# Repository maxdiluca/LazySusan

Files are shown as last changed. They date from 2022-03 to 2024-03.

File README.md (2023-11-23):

# Arduino-based Lazy Susan

<p>This project has been funded by the Experimental Psychology Society and has been developed by <a href="https://massimilianodiluca.info/">Max Di Luca</a>.</p>

<p align="left">

 Judgments about material properties (e.g., roughness, softness, temperature extraction) are acquired through direct contact between skin with a surface and through exploration. Presenting materials to participant can be an exhausting task for the experimenter, and mechanical automation is a desired methodology. Moreover, due to social distancing requirements, in-person experiments to study how the perception of these properties is achieved, might not be possible. To overcome these limitations, here we devised a setup that can be either used to present objects to participants, it could be mailed to participants’ homes with instructions on how to run the experiment and collect the data, or that can be employed in conjunction with a VR headset to create visual-haptic discrepancies between material properties.
 
 The device is built by combining an inexpensive lazy Susan with a microcontroller (Atmega168). Precisely manufactured 3D printed surfaces are mounted on the motorized lazy Susan and the microcontroller allows rapid selection of the appropriate sample. 

 </p>
 <p align="left">
 <br>
 The code to control the experiment is included in this repository.
 
  </p>
 <p align="centre">

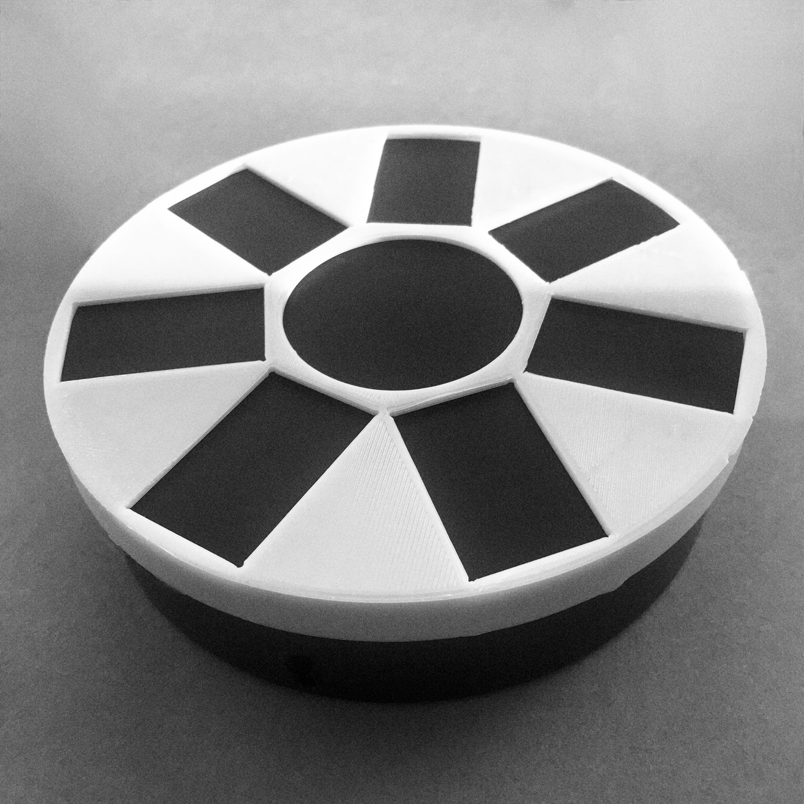
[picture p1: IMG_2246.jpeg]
 

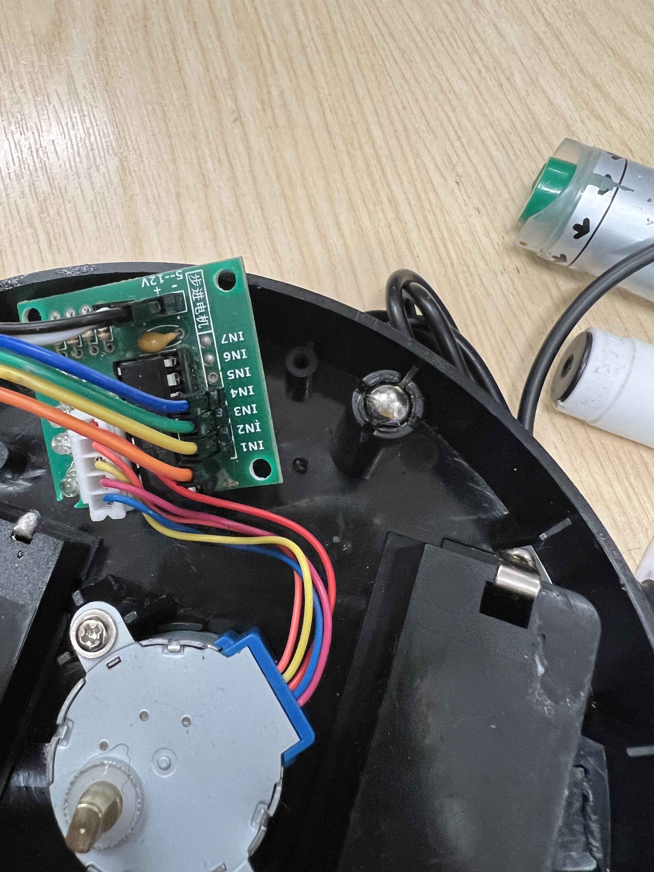
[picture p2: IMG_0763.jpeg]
  
  </p>
 <p align="centre">
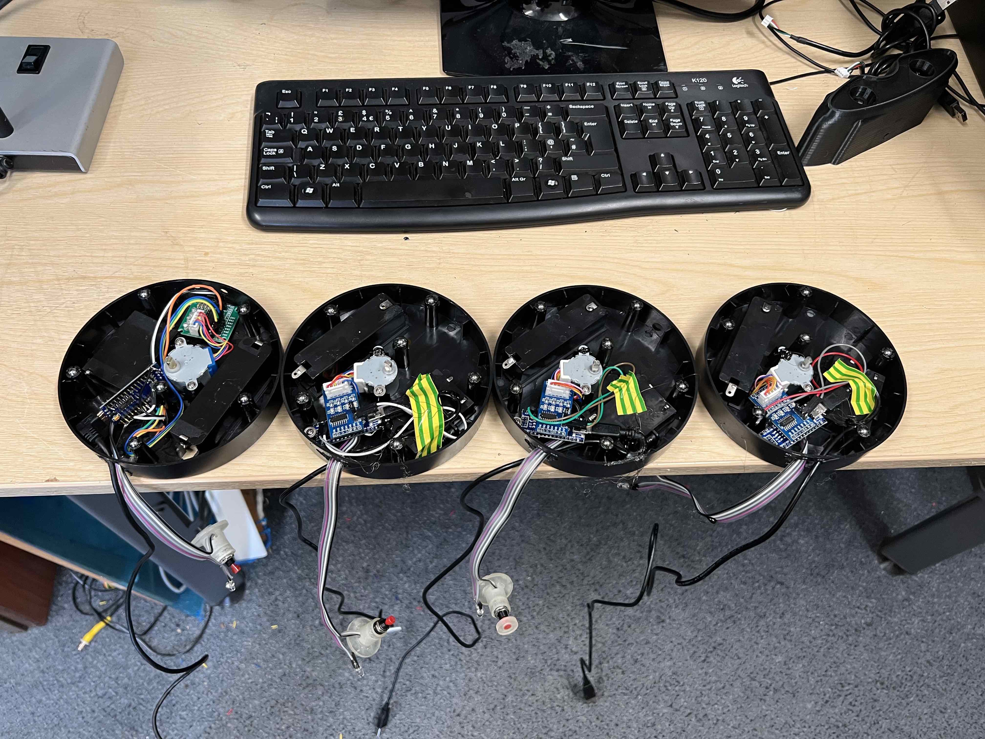
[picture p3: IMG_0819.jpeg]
   <br> 
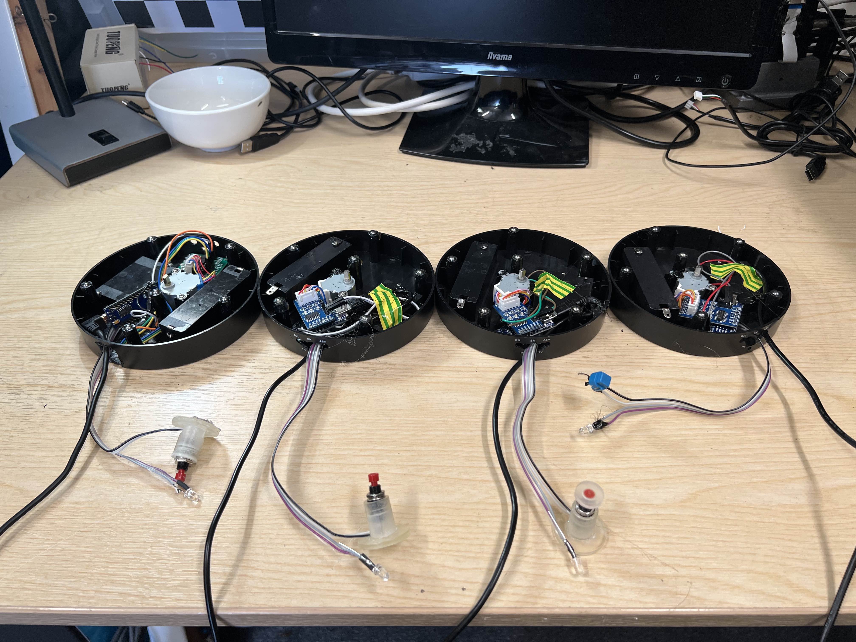
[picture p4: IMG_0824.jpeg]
    
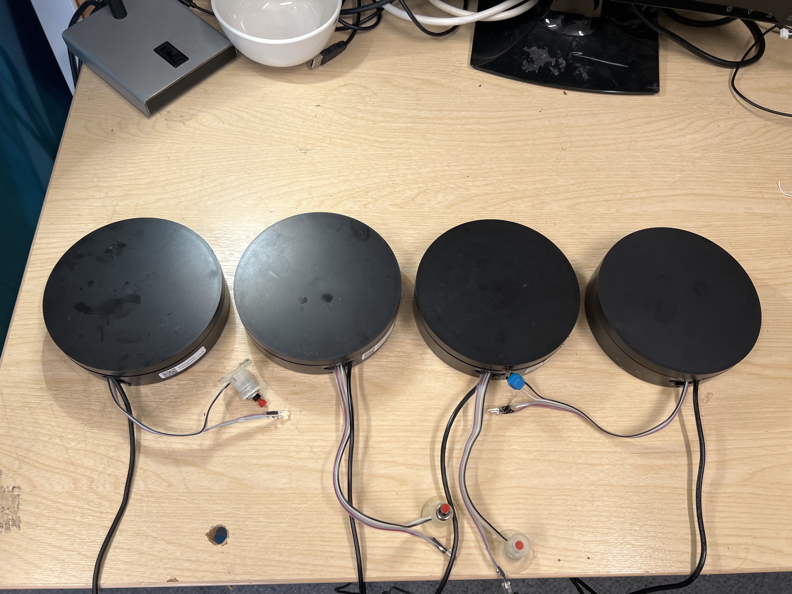
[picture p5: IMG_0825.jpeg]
    
   </p>
 <p align="centre">
  <br>
  
 <video controls="controls" width="420" height="315" name="Video Name">
  <source src="./IMG_0762.MOV">
</video>

  <br>
  <object data="http://www.youtube.com/embed/Hrc2zLRdNaU"
  width="420" height="315"></object>
 
</p>

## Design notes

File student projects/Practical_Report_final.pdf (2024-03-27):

## University of Birmingham

## School of Psychology

## Assessment Submission Form

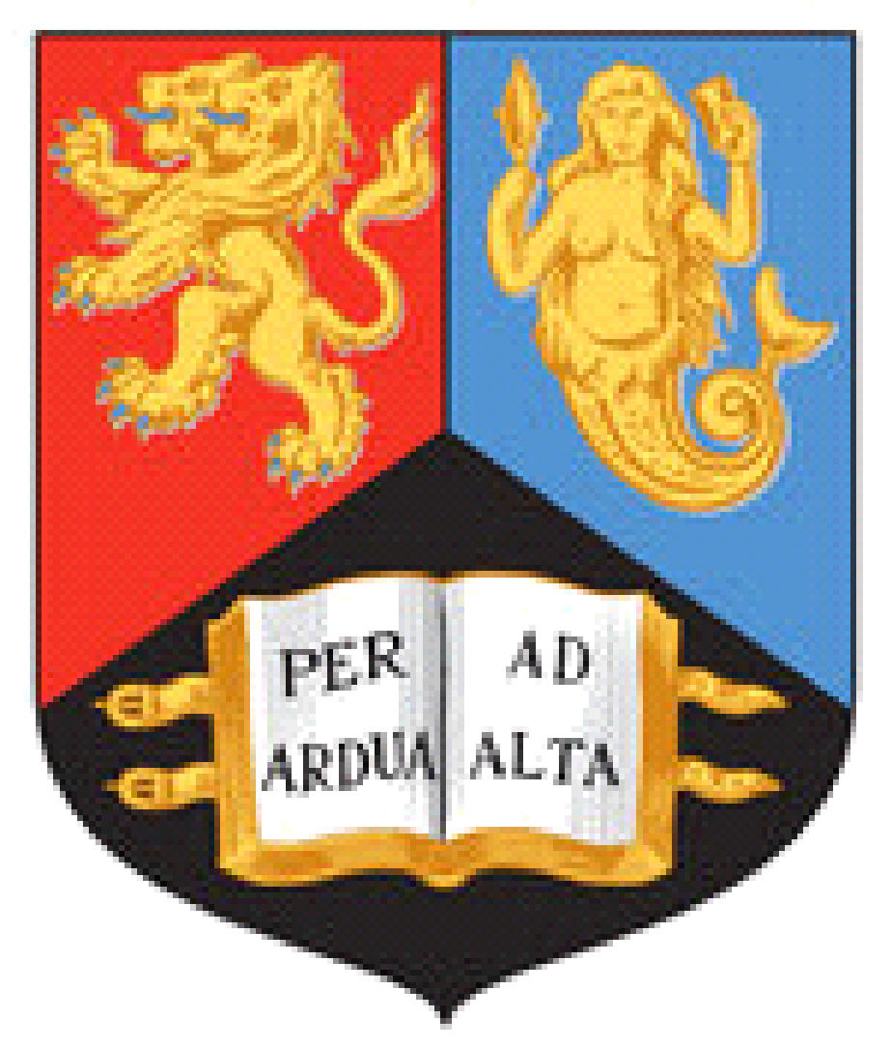
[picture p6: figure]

The purpose of this coversheet is to ensure you receive targeted feedback that will support your learning. Please complete all sections and use this template to start your written assignments.

Student ID: | 2261842
Programme: | Postgraduate
Module title: | Current Research and Practice

Assessment type:

Title of your report: | Arduino robot for tactile psychophysics
Word count: | 1739

I am happy for my assignment to be considered for inclusion as an anonymised
exemplar in the Psychology Bank of Assessed Work. | ☐ Yes | ☐ No

Reflection on previous feedback (max. 60 words):
Write a brief comment about something that you have tried to implement in the current piece in response to previous feedback: e.g. "I have been told that I need to include an opening paragraph that identifies the purpose of the piece. I have tried to address this here."

Request for particular attention to be paid (max. 60 words):
Identify an area for which you would particularly like feedback: e.g. “Please comment on the coherence of my piece as a whole. Are my arguments fully developed?”

Arduino robot for tactile psychophysics

2261842

School of Psychology

University of Birmingham

## Introduction

The primary purpose of this study is to obtain a basic understanding of phycological methods and Arduino programming to implement an experimental environment. Then, analyse the data to estimate perception judgement on Matlab. We have learned specific techniques to test sensory information like auditory sensation and tactile. Furthermore, the codes should be created enough to launch the open-source software project of this demonstration.

Psychophysics
Psychophysics has been the main focus of research for a long time as it is vital to investigate how perception is accomplished (Stevens, 1960).
The history of psychology started in 1824 by Johann Herbart, recognised as a father of educational psychology (Hoose, 2021). He was not a usual teacher that developed his method and taught it to the students. He highlighted the significance of the relationship between the physical environment and the state of mind. Then, some researchers had gradually solidified the concept of psychology; for example, weber studied the time of action by the weight of objects in 1834. As a whole, this subject is the part of science defining the relationship between physical occasions and psychological experiences—the purpose of this study is to solve these connections, not only the measurements. Some of the keywords in this subject are Quantitative and Objective to define the relationship (Ingleby, 1967). One of the good examples of quantitative is the situation during the class, as the number of photos on screen and brightness. Having this quantitative analysis, humans can explore inter-species or inter-subjects stimulus and perception. The sense of texture is one of the numerous essential research topics in this field, and the experiments carried out here deal with the subject accordingly.

Magnitude Estimation
Magnitude Estimation is one of the essential methods in psychology to create numerical data for the intensity of perception of physical stimuli such as sound and tactile (Huang and Griffin, 2014). Using this method, people can analyse the connection between biological information and perception. If the stimulus intensity will be two times larger than the previous one, the estimation rate should be twice as high (Luca, 2014). In this research, participants were tested by the Absolute Magnitude Estimation(AME) method, a type of Magnitude Estimation without reference information. They had to determine numerical values for roughness without any prior knowledge.

Weber–Fechner Law
A law that describes the different thresholds for sensory information was formalised by Weber in the early history of Psychology, which was in the nineteenth century. He was able to find that the threshold for discriminating a stimulus is balanced to its intensity. The intensity of a feeling is not subjective and can only be measured relatively. In other words, if the ratio of stimuli is the same in different situations, the difference in sensation received is to be equal (Nutter and Esker, 2006). This law is known as below:

ΔI/I = K

Where K is a constant, and I is the expected value of the stimulus.
Gustav Fechner expanded the law by emanating a relationship between a stimulus and the estimated magnitude (Stevens, 1961). According to the discovery, the rate of sensory quantity is inversely proportional to the intensity of the stimulus. Also, it is proportional to the increment of the stimulus. He derived the mathematical relationship from these relationships.

### P = K log I

Where K is constant, P is the perceived sensory, I is the intensity of stimuli. To conclude, he found that sensory volume is proportional to the logarithm of the stimulus volume. Currently, this law is called Weber–Fechner Law since this finding is based on Weber's law.

## Implementation

Arduino software
Arduino is an open-source software platform to write and read codes in microcontrollers connecting buttons, sensors, or motors(https://www.arduino.cc/en/Guide/Introduction). We can write codes in C++, which contains three main parts, functions, values, and structure. Thanks to the easiness of getting started experiments, quite a few people have used Arduino in recent years worldwide, not only for simple tasks but also for complicated scientific ones. There are some reasons why it has been chosen. One of the principal reasons is that the simple way of using this platform has allowed both teachers and students low cost. Moreover, developers do not need to prepare specific machines because they run on any operating system.

Establishing the environment
STM32 was used to create the environment for this experiment. This microcomputer delivers the basis for building embedded systems at affordable costs. Coding for this device is done using an Arduino, which may not be as good as the Arduino hardware in terms of detail. Still, it can basically provide the functionality needed for development (Ersin, 2022). This computer was programmed to use a stepper motor in the study, which revolved to set plates for the experiment.
Nonetheless, I had to attach an output device to it as there was only an input function.
For this reason, there were mainly three kinds of apparatus in this device: input board, output board, and stepper motor. The stepper motor has electrodes in each of the four directions. Increasing or decreasing the input value of each enables the reproduction of various movements, not only in the forward direction. The table type in this research is customarily called Lazy Susan, which is able to rotate to cope with the stepper motor's rotation. The table has four holes at 90 degrees intervals into which the boards used in the experiments are inserted.

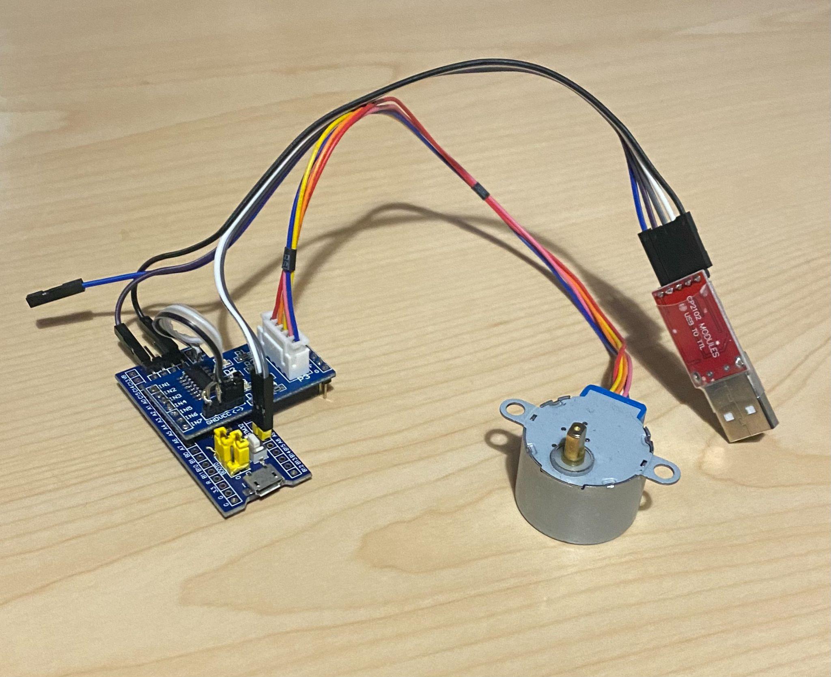
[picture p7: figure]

Picture1 STM32 device with Stepper motor

Programming
With regard to programming, I used Stepper.h function from Arduino, which enables us to use a stepper motor with ease. After setting the values to rotate at 90 degrees, the input ports connected to each direction are matched and initialised. The setup function determines the speed of the rotation.
The table was set to rotate in the loop function. After that, the motor was designed to rotate at regular intervals to trace the finger by setting the number of moving times.
Consequently, the experimental procedure is as follows:

1: Touch the board in front of the participant
2: Record the value of the surface roughness
2: Revolve the device at 90 degrees
3: Back to step 1 until one revolution

Actually, the practice is done before step 1. This practice has nothing to do with programming, so I will not go into detail but will explain it adequately later.

#include <Stepper.h>

const int stepsPerRotation = 514; //set the num to rotate 90 degrees per movement // initialize the stepper which uses from 1 to 4
Stepper myStepper(stepsPerRotation, 3, 1, 2, 4);

void setup() {
// set the speed at 30rpm: myStepper.setSpeed(30);
}

void loop() {
// step fixed degree in one direction: myStepper.step(stepsPerRotation); // make waiting time to touch the board delay(1500);

}

## Methodology

The roughness of the plates is from 1800mm to 4200mm, as shown in the following picture. Each plate has a shallow groove dug in the front made through a 3D printer. There were 6 participants in this experiment. They were instructed to answer how rough the surface was for four different plates using a scale from 1 to
10. In addition, they had to brush the plate just once by finger pad actively. Before the experiment, subjects practised understanding how to do it with a random sample, without any prior information about that sample. After that, the participants would check the roughness of the boards four times in a row with their eyes closed. The boards were placed on the lazy susan table that revolves to make plates located in front of the players. The number of times per board was used varied a little, as it was decided entirely at random which board to use. There was a difference of up to two times. However, as the number of times each board was used was close to the average, it was decided that this did not have any particular influence on the results.

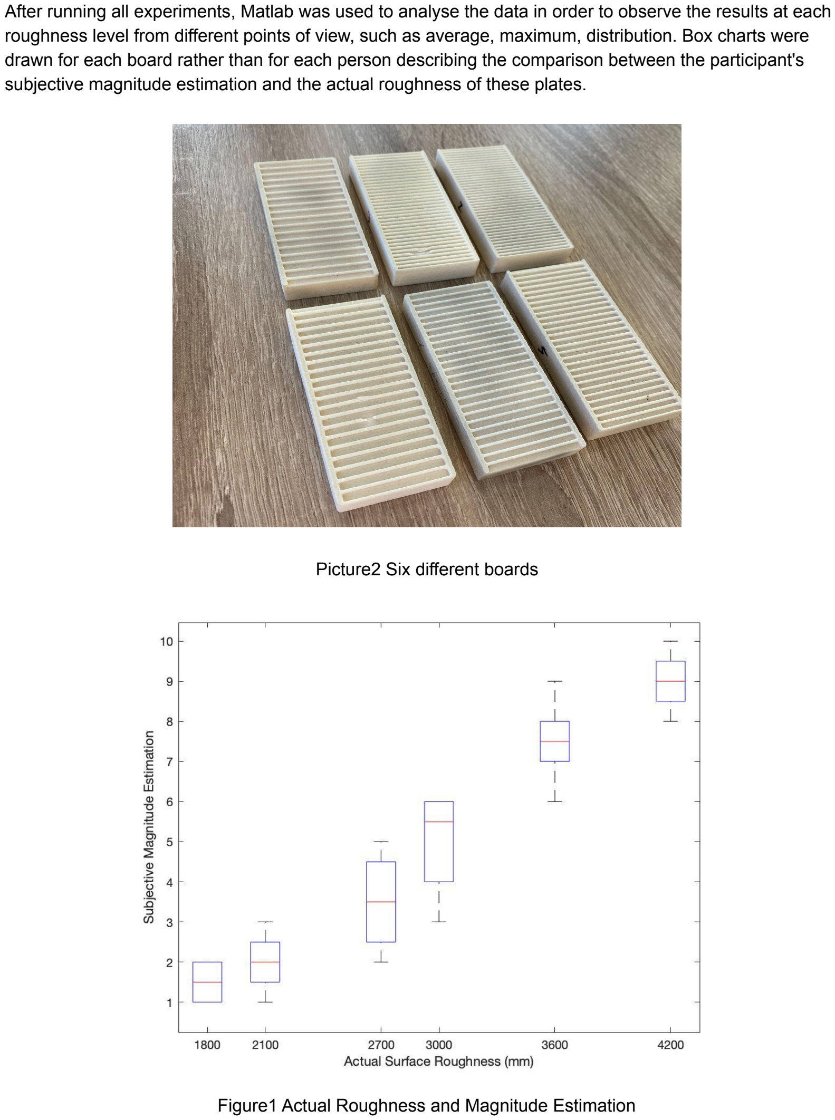
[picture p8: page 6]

After running all experiments, Matlab was used to analyse the data in order to observe the results at each roughness level from different points of view, such as average, maximum, distribution. Box charts were drawn for each board rather than for each person describing the comparison between the participant's subjective magnitude estimation and the actual roughness of these plates.

Picture2 Six different boards

Figure1 Actual Roughness and Magnitude Estimation

## Result

According to the results, it is clear that the subject's tactile perception has a strong correlation with the actual roughness. The more actual roughness saw an increase, participants felt more muscular stimuli. Nevertheless, it was challenging to compare the strength of stimuli precisely since the speed of moving by finger differed each step and amongst participants, which is impossible to make players keep the same pace in each experiment. Because of this, the subjective perception did not follow the Weber–Fechner Law. Although there was a correlation, it was not proportional to the logarithm.

## Conclusion

Through this experiment, I was able to achieve the first goal. In terms of theory, we have been able to link each theory and understand it systematically. Also, I was able to achieve an ideal design for the assembly and programming of the device and perform the experiment as wanted, including the plotting in Matlab. We did not focus on the results of the experiments, so I was not able to discuss them sufficiently. It will be necessary to pay more attention to details in future work.

## References

Stevens, S. S, 1960. THE PSYCHOPHYSICS OF SENSORY FUNCTION. American Scientist 48(2), pp.226-254.

Hoose, N., 2021. History of Educational Psychology | Educational Psychology. [online]
Courses.lumenlearning.com. Available at: <https://courses.lumenlearning.com/edpsy/chapter/history-of-educational-psychology/>

Ingleby, J., 1967. Signal detection theory and psychophysics. Journal of Sound and Vibration, 5(3), pp.519-521.
Huang, Y. and Griffin, M., 2014. Comparison of absolute magnitude estimation and relative magnitude estimation for judging the subjective intensity of noise and vibration. Applied Acoustics, 77, pp.82-88.

Hellman, R. and Zwislocki, J., 1968. Loudness Determination at Low Sound Frequencies. The Journal of the Acoustical Society of America, 43(1), pp.60-64.

Luca, M., 2014. Multisensory softness. Springer, p.5.

Nutter, F. and Esker, P., 2006. The Role of Psychophysics in Phytopathology: The Weber–Fechner Law Revisited. European Journal of Plant Pathology, 114(2), pp.199-213.

Ersin, F., 2022. Discovering the STM32 Microcontroller. [online] Academia.edu. Available at: <https://www.academia.edu/39370699/Discovering_the_STM32_Microcontroller> [Accessed 12 January 2022].

Stevens, S., 1961. To Honor Fechner and Repeal His Law. Science, 133(3446), pp.80-86.

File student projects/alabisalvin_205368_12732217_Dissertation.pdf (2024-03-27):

An investigation into multidimensionality of Tactile Perception: Is the perception of roughness influenced by other modalities such as Vision?

An investigation into multidimensionality of Tactile Perception: Is the perception of roughness influenced by other modalities such as Vision?

University of Birmingham

Student ID: 2004878

Word Count: 3401

Abstract

The haptic sense gives individuals the ability to be able to find out information about the

properties of a material or an object. The main aspects of object properties that are

extensively studied are roughness smoothness and friction. Roughness is defined as a

material that possesses an uneven irregular surface texture. Most research investigating

haptic perception has not practically explored the multidimensionality of touch as a whole

and studied with purely just exploration of the finger over various surfaces. This research

attempts to extend theoretical information about haptic perception by studying the influence

of Vision as a sensory modality on tactile perception. This is to provide empirical evidence

that Haptic perception is multifaceted. In this study, Absolute magnitude estimation (a

procedure that allows participants to numerically rate roughness on a scale of their own) was

used. The assumption would be the higher the estimates the rougher the participant judges

the 3D blocks. This estimation was used on 7 3D models of textile blocks of varying

roughness displayed on a lazy Susan turntable. Participants had to give an estimated rating

of roughness in three conditions Visual where participants-based estimations on sight alone,

visual-haptic where the participants are not blindfolded and can touch the samples, haptic

conditions where participants are blindfolded. The hypothesis explored was there will be a

significant difference in the AME ratings of roughness across all three conditions and there

would be higher mean AME ratings in the visual haptic condition. This would indicate that

vision exerts an influence on roughness perception. Results displayed a significant main

effect of visual modalities on roughness perception and a larger mean average rating in the

Visual Haptic condition. Although unable to find significant interactions between conditions

the hypothesis was partly supported as with the significant main effect found there is a clear

difference in the way different modalities such as vision process tactile discrimination which

establishes that Haptic Perception is solely refined to touch as a sensory modality. These

future considerations could made be made studying other dimensions such as finer textures

(smoothness), and other cases where vision isn’t readily accessible in Blind individuals.

Introduction

Touch is a significant part of the five senses and haptic perception, in particular, refers to the

ability to perceive and identify specific characteristics of objects like texture, vibration,

temperature, or pressure. Buried under both hairy and hairless skin are biological

mechanisms otherwise known as cutaneous mechanoreceptors that facilitate haptic

perception. The four cutaneous receptors found across the body (Merkel disc, Pacinian

capsule, Ruffini endings, and Meisner Corpuscles) are divided into two categories - slow

adapting receptors which produce responses to sustained pressure, and fast adapting

receptors which produce fast responses to skin deformation. These receptors play a key

role in the haptic perception of texture which is best exemplified by SA1 receptors which are

slow adapting and the perception of surface roughness. Research into the field of haptic

perception has focussed on these specific receptors and has produced evidence that proves

the isolation of specific touch receptors. (Klatzky and Lederman 1985) highlighted that these

receptors are implicated in the “What System” which processes surface objects and

properties. This system is the main focus of this research with the objective to understand

how it is influenced by visual modalities.

There has been extensive focus on key characteristics of texture within the field of tactile

perception. (Okamoto et al’s 2012) review of current research into tactile perception provides a

salient overview of studies that have investigated subjective ratings of materials with a specific

focus on macro vs fine roughness, hardness vs softness, and friction. Key in this study is

(Tanaka et al 2008’s) roughness, moistness, hardness, and warmness examination of thirteen

textiles including cotton and silk. In this study, twenty-one participants were blindfolded and

instructed to rate textiles according to seven adjective pairs - this is known as the Classification

Method wherein ranking is based on similarities between materials. This methodological design

as well as a focus on roughness is a prominent feature of studies in Okamoto's research

summary and is indicative of a research methodology within a haptic perception study that only

establishes textures that belong to one class. In doing so, there is oversight of subclasses of

texture which can impact the classification between textures.

Included in Okamoto’s research summary are other critical ways of investigating subjective

ratings between materials such as the semantic different method (Osgood et al 1957) and

the similarity estimation method. These methods share some similarities with the

Classification Methods as they place an emphasis on ranking based on adjective labels

while eschewing the focus on subjectivity. The Similarity Estimation Method involves a triad of group ratio judgments, grading a method evident in(Cho et als 2001) research into reliability

judgments on visual textured stimuli, visual analog scaling, and numerical scaling, and the

Semantic Different Methods allows participants to rate materials on a continuum one by one

using a scale that has rough on one end and smooth on the opposite end. Despite both methods

embrace of some quantitative methodology, the process is often convoluted and difficult to

explain to participants, taking away focus from the experiment. The Absolute Magnitude

Estimation Method (Stevens et al 2017) combines subjectivity, numerical value, and ease for

haptic perception research. It is a psychophysical procedure in which participants make

subjective judgments about the magnitude of stimuli with their own numerical scale. Research by

(Verillo et al 1999) utilized AME with subjective judgments of eleven sandpaper samples to

investigate whether there is a significant difference in ratings of roughness between the thumb

and the finger. In this research, the stimulus was rectangular in the shape of standard sandpaper

which was attached to plates of steel. The samples ranged from 16 to 905mm in terms of particle

diameters and were presented to the participants three times in random order to prevent the

order effect. The geometric mean for each participant which is described as Ms was then divided

by the grand geometric mean for all the participants for all the grit sizes of the samples. This

created the normalized responses for each participant to be analyzed using Repeated Measures

ANOVA. The same procedure will be adopted where participants were asked to graze the 3D

sample and rate the roughness with any scale they choose. The ratings were then normalized by

calculating the mean making it easier to analyze. For the reasons relayed above, this research

will incorporate absolute magnitude estimation method into the results.

The use of sandpaper to test roughness as evident in (Verillo et al 1999) research has been

replicated through the research into haptic perception. However, (Weber et al 2013)

suggested that samples like sandpapers often vary significantly among different

manufacturers and the raised grits will not be similar in shape and size. The use of 3D

manufactured raised patterns was encouraged in (Tymms et al 2018) research as it allowed

“precise surface geometry “which gives the researchers more control over the arrangement

of textons in a quick process of printing. This will be incorporated into this research as an

improvement on previous studies into tactile perception.

Within Okamoto et al’s research summary paper, it is clear that research into haptic

perception focussed on participants’ ability to distinguish between materials solely using

touch. Examinations into the multidimensionality of touch, that is the influence of the other four senses on haptic perception is fairly rare. (Heller et al 1982) analyzed the influence of

vision on haptic perception in sighted and non-sighted participants. The experiment involved

four Japanese abrasive sharpening stones with sighted participants instructed to point to

the stimuli which would be the smoothest of the four abrasive stones. Participants in the

sight condition were given noise-canceling headphones to cancel out auditory variables and

told to pick objects that were smooth. Participants in the touch condition were asked to pick

the objects they thought were smooth.

Results showed that individuals performed better in the touch condition than in the vision

condition. It was then concluded that sight was not sufficient for detecting smoother textures and

perhaps touch may be superior to visual modalities in tactile perception. Whilst this is concluded

it is further suggested by (Heller et al 1982) that coarser surfaces with larger textural features

can be detected by sight, but finer surfaces may be difficult. Nevertheless, there is an influence

of visual modalities on detecting textural features which will be explored further in this research

experiment. This study will incorporate surface roughness as opposed to smoothness in (Heller

et al 1982) study and use this information to find out how other modalities influence the detection

of textures. There is some neurological evidence that could provide further support for the

influence of visual modalities on tactile processing. This is evident in (Sathian et al 2002)who

indicated that visual imagery is necessary for tactile processing of properties of certain objects.

Participants were asked to determine the orientation of plastic gratings that was applied to the

finger pads. They were asked to report whether the gratings were orientated along or laterally

across the finger. TMS (Transcranial Magnetic Stimulation) was applied to the occipital areas of

participants and the results indicated a disruption in performance in the orientation task. This led

to the conclusion that visual processing is necessary for tactile discrimination further established

participants reported that they could feel the gratings but were unclear on the orientation of the

gratings during occipital TMS. This reinforces the thesis that tactile perception isn’t unitary and

other modalities such as vision could interact with tactile systems which establishes a

multidimensional system.

The aim of this study is to establish whether vision has an influence on tactile perception

which would be investigated in conditions where vision is isolated and where vision and

tactile perception is present. Thus, the outcome would be to observe whether perceptual

discrimination of textures is dissimilar across conditions. The importance of this is indicated

in amputees who are unable to feel senses of the world around them with prosthetic limbs.

The information of the combination of haptic information and visual information and how that

can improve prosthetic technology could help aid the tactile perception of individuals with missing limbs. To further provide support for future implications for this research (Timm et al

2020) indicated a mechanical glove that could initiate plasticity at the fingertips to improve

tactile discrimination. The glove induced frequency-specific stimulation to fingertips that

improved performance in tactile orientation tasks and two-point discrimination. The

prediction of the study is that there will be a significant difference between the AME ratings

of the visual condition, visual Haptic condition, and tactile condition and there would be a

higher mean AME rating in the Visual haptic condition. The methodology of the research

draws on some principles of psychophysics which is the study of determining the

mathematical relation between physical stimuli and human tactual sensory experience. The

method will include three conditions, one condition will be that participants will be

blindfolded and touch the samples, another condition will involve participants subjectively

judging material solely based on visual observation, and another will be visual- haptic where

they see the stimuli whilst touching them

Methods

Participants and Design: Participants included 12 participants (5 males, 7 males, range 20-

21) from the University of Birmingham. The exclusion criteria were suggested in the consent

form advertised as only right-handed people were selected which is the inclusion criteria for

right-handed participants. The informed consent form is included in appendix A. There were

no finger injuries and all participants had to use their index fingers to graze the samples.

Appendix A contains the general information about the consent form and safety screening

questionnaire. All participants gave informed consent and ethical procedures were adhered

to according to the British Psychology Association. The design was set up as 3(sensory

conditions) X1(Absolute Magnitude estimation).

Materials: The stimuli included 3D printed texture blocks (fig 1) all different textures ranging

from numbers displayed on the back to signify this. The rectangular blocks were measured

3.9cmX 2.5cm which was all identical for all the blocks. The experiment made use of a Lazy

Susan turntable fig 2. The 3D printed surfaces are mounted on the Lazy Susan and there is

a micro-controller (ATmega168) within this machine that allows quick selection of the correct

sample. The turntable turns clockwise with the code uploaded to the machine. This in turn

reduces the order effect so participants don’t select the same samples. The program used to

power the lazy Susan was Arduino Idea coding program on Windows Computer. These

programmed serial numbers (see Appendix B) corresponded with the order in which the 3D

samples were selected by the participants. An opaque Blindfold was used in the Haptic

condition.

Figure 1: Seven 3D oriented blocks all arranged in order smooth to rough

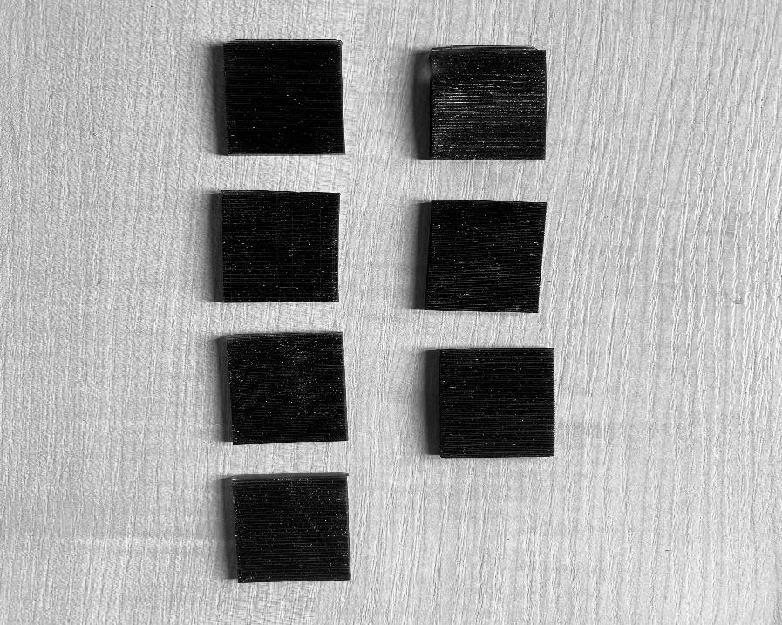
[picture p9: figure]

Procedure: This is a Within measures Design as all participants experience all three

conditions. The three conditions were all counterbalanced to avoid the order effect and a

typical trial is displayed in figure 3. One condition is the Haptic condition where the

participant is guided to press the red button which randomizes the selection of the seven

stimuli displayed in fig 1. This condition requires the participant to be blindfolded to isolate

the experience to haptic perception only. The participants were asked to graze vertically up

and down the textile and the amount was three times for standardization. This block is

repeated three times with different orders of the sample presented. The participant was then

asked to give an absolute magnitude estimation of roughness which is a numerical estimate

based on any scale of the participants choosing as evident in Verrilli et al research.

Condition B is the Visual condition in which participants were asked not to touch the samples

and judge roughness based on vision alone. The same AME was asked of this participant in

this condition as well. Condition C is the visual haptic condition where the participants did not

need to be blindfolded and they were asked to give an AME rating after touching the

randomly selected samples. All conditions had 3 Repetitions. All AME were recorded in an

excel spreadsheet (Appendix C)

Figure 2: Dissected Lazy Susan Turntable with USB and Button programmer attached

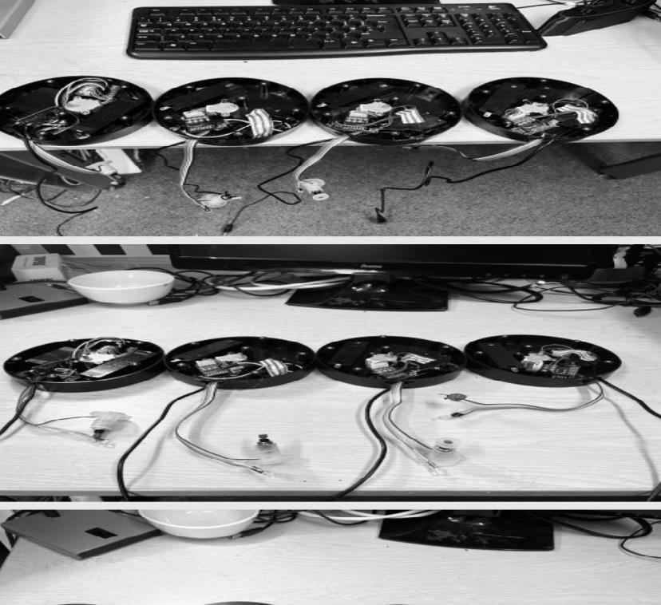
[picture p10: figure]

Figure 3: Display of a trial with participant grazing the sample vertically as signified by

the arrow

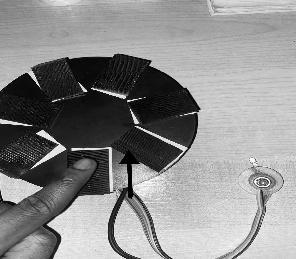
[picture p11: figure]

Analysis:

All Data was analysed using SPSS 27 a statistics package and with it, a Repeated

Measures ANOVA was applied to the data using Sphericity assumed correction if needed.

The Absolute magnitude estimations were normalized using the equation from Verillo et al

(1999)`s study which is stated as the MS (geometric mean) of ratings of all three blocks

divided by the grand mean (MG). The normalization was done for all the conditions, and this

was the data that was put through Repeated Measures ANOVA. The reason for

normalization is evident in (Moskowitz et al 1971) who pointed out in magnitude estimation

procedures normalization is necessary when some participants give a large number

estimate and others give a smaller range of estimates. A test of normality was applied to the

data before analysis to indicate whether the data fit parametric assumptions and this, in turn,

allowed for Repeated Measured Anova to be ran.

Results

The SPSS output shows the within-subjects factor was the Sensory Modalities which is the

conditions of Visual, Visual Haptic, Haptic. The results from the Repeated measures ANOVA

indicates F(2,22)=4.882, p=.018,etap2=.307 The significant value for sphericity was 0.444 which

is greater than 0.05. Thus, sphericity could be assumed in the data and as reported the ANOVA

result was referred to in the sphericity assumed row. The result was significant which supports

predictions made in this current experiment. The pairwise comparisons suggested there wasn’t

a significant interaction between Visual, Visual Haptic, and Haptic conditions. This is indicated

as the p-value between Visual and Haptic conditions was reported as p=0.535 and the p-value

between haptic and Visual haptic was p=0.065. Fig 4 shows the mean absolute magnitude

estimations against the sensory three conditions. The mean and standard deviation of the

ratings in all three conditions are reported in Table 1 It is reported that the mean of AME in the

Visual Haptic condition is 8.3 which is higher than the other conditions that report 5.3(haptic)

and 6.4 (Visual). All in all, the Results partly support the hypothesis that there will be a

significant difference in ratings between the three conditions of Visual Haptic and Visual

Haptic.

Fig 4: Figure depicting means of AME against Visual, Haptic, And Visual Haptic (error

bars represent standard errors)

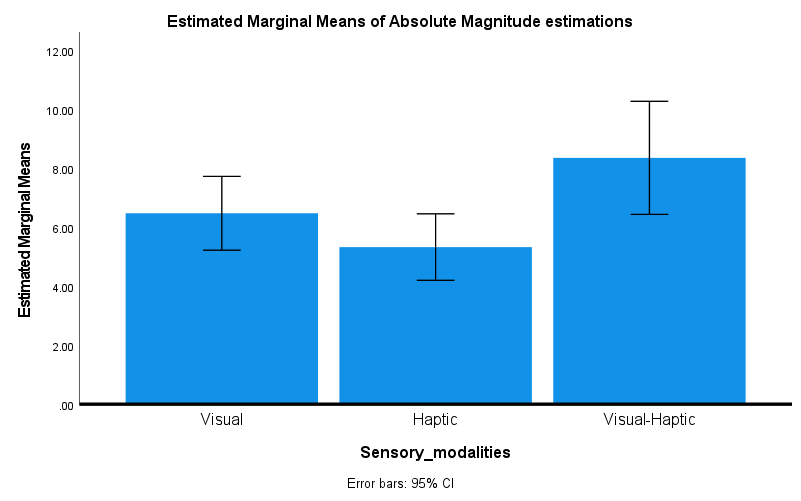
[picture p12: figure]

Table 1: Table showing Mean of AME ratings for all three conditions (Visual , Haptic, Visual

Haptic)

Estimates

Measure: MEASURE_1

Sensory_modaliti

es | Mean | Std.
| | Error

95% Confidence Interval

| | | Lower | Upper
| | | Bound | Bound
1 | 6.481 | .569 | 5.229 | 7.733
2 | 5.333 | .512 | 4.205 | 6.461
3 | 8.362 | .872 | 6.443 | 10.280

Discussion

The aim of this current research was to investigate whether visual modalities had an

influence on Haptic perception and therefore establish that Haptic Perception is Multifaceted.

The hypothesis that stemmed from this is that there will be a significant difference in the

AME ratings of the three conditions of VH, Visual, and Haptic. The results partly support the

hypothesis as a significant main effect was found. This in accordance with the higher mean

AME ratings in the visual haptic condition could suggest that there is a mechanism in Visual

modalities that interferes with individuals’ discrimination of rough textures. The surface

characteristics and the outward appearance of the 3D samples are what perhaps produced

the higher mean ratings observed. The results support the conclusions made by (Heller et al

1982)and (Sathian et al 2002) that visual modalities do influence tactile perception as it

interacts with discrimination of certain textural features highlighted such as surface

roughness, and the overall appearance of ridges displayed on the 3D printed samples. The

dominance of visual modalities displayed in the VH condition has been explained by the

modality appropriateness hypothesis (Welch et al 1986) and the directed attention

hypothesis (Posner et al 1976). MAH explains that individuals rely on the modality that is

specific for a task and in this experiment, it was to describe numerically the level of

roughness of the samples. DAH indicates that individuals direct their attention to the visual

modality on a usual basis and this concentration takes away from less attention to modalities

such as touch.

.The paired comparison results were unexpected and deviates from the ANOVA result as it

was not significant. It revealed there isn’t a significant interaction between the mean AME

ratings. The reason for this may be down to certain methodological drawbacks. The study

involved a rudimental explanation of absolute magnitude estimation to participants before the

actual procedure began and this may be a limitation as it could explain the similarity in

ratings between all three trials as it was observed participants has a specific range and

subconsciously stuck to that range for the subsequent trials. The similarity in range occurred

across all conditions and it could be the reason for the lack of significance of ratings between

the conditions. Research by (Collins et al 2012) made us of absolute magnitude estimation in

investigating loudness in children and before the actual procedure had participants undergo

training in estimating line lengths. ( Stevens et al 2017)posited that line estimation is a task

that which participants can get a quick grasp of AME. This was also explored in( Verillo et als

1999)as the original testing included participant estimating line lengths. This could perhaps

be an improvement in ratings given in the experiment and perhaps go towards producing more significant differences between the conditions as there is more of a

range in numerical estimates.

The numerical estimates of roughness were solely on this dimension and future studies

could implement other dimensions referenced in Okamamoto et als study (2012). This is an

effort to distinguish if the same interaction of visual modalities influencing haptic perception

remains the same across ratings of other dimensions such as surface texture, glossiness,

and brightness. This would further establish the fact that Tactile perception in an everyday

environment where a range of dimensions is explored requires the collaboration of other

modalities such as vision. Research exploring other dimensions includes (Yoshida et al

1968) who investigated similar conditions of haptic only visual only and visual haptic. The

study reviewed dimensions such as slippery sticky hard/soft and rough smooth. Thus, if a

similar methodological design studied in this current experiment could be attributed to

these dimensions, it could reveal if visual modalities influence tactile perception and

produce different AME ratings in the three conditions. It could also reveal that perhaps for

certain dimensions vision is inferior and tactile perception is more accurate in discrimination

between textures.

Whilst this discrimination between textures is aided by Vision it is unclear whether Touch or

Visual modalities produce confident ratings in conditions where the samples are not identical

and clear cut. This is evident in research by (Fairhurst et al 2018) who investigated

perceptual ambiguity where participants explored T-shaped samples that were inverted. In

different blocks, the stimuli had either clear cut or ambiguous cases and judgments based

on whether the vertical bar was shorter or longer than the horizontal bar. The confidence in

rating was tested and results indicated more confidence in Tactile when the case was

ambiguous but more confidence in Visual Modalities when the case was clear cut. This links

to the earlier aforementioned point that for certain textures in which case finer textures vision

is seen as more readily accessible to use but for more ambiguous textures it requires more

exploration to discriminate. This is an avenue that could be explored In future considerations

as from the results in the study it is only clear vision has an influence in AME ratings of

similarly printed 3D Samples but one could attribute different conditions with various

samples of varying ambiguity to see how extensive and multifaceted Haptic perception is as

a whole across a range of textures.

Potential Follow up studies from the significant differences found in the three conditions

could perhaps delve into the outcomes of tactile accuracy in the absence of blindness. This

would perhaps provide more theoretical information about the interaction between senses

and how that affects haptic perception. A key example is with blind individuals and how the absence of vision disrupts haptic perception which was created artificially with the blindfold

in this current experiment in the haptic condition. Research by (Bhattacharjee et al 2010)

found that blind individuals who experienced vision at an early stage and later acquired

blindness perform better on tests of tactile discrimination than sighted individuals. The test

required participants to distinguish between small taps and large taps on a small probe that

produced vibrations. When the large longer tap followed a smaller tap it disrupted tactile

discrimination, but it was found that blind individuals performed better in these trials. This

establishes the malleability of tactile perception and its performance when vision is impaired.

The ability of the brain to compensate for the absence supports the Multidimensionality

thesis as if the tactile perception was solely reduced to touch alone then Blind individuals

would not possess the ability of tactile discrimination. This Is further supported by research

that indicated that visual cortexes are activated in tactile discrimination tasks which produces

the conclusion that the brain can use systems associated with other modalities to aid the

perception of textures.

In conclusion, the experiment further expanded on previous research into Haptic perception

establishing that it is multifacetedly evidenced by the fact that Visual modalities influence

Absolute Magnitude estimation ratings. Results partly supported the hypothesis that there

will be a significant difference between the three conditions, whilst there wasn’t a significant

interaction between the three conditions. There are some methodological limitations in

future studies could address and It provides enough information to aid tactile technology

earlier mentioned and provide more information on how senses interact with each other to

aid haptic perception when one modality is damaged.

References

Bhattacharjee, A., Amanda, J. Y., Lisak, J. A., Vargas, M. G., & Goldreich, D. (2010).

Vibrotactile masking experiments reveal accelerated somatosensory processing in

congenitally blind braille readers. Journal of Neuroscience, 30(43), 14288-14298.

Cho, R. Y., Yang, V., & Hallett, P. E. (2000). Reliability and dimensionality of judgments

of visually textured materials. Perception & Psychophysics, 62(4), 735-752.

Cho, G., Casali, J. G., & Yi, E. (2001). Effect of fabric sound and touch on human

subjective sensation. Fibers and Polymers, 2(4), 196-202.

Fairhurst, M. T., Travers, E., Hayward, V., & Deroy, O. (2018). Confidence is higher in touch

than in vision in cases of perceptual ambiguity. Scientific Reports, 8(1), 1-9.

Klatzky, R. L., Lederman, S. J., & Metzger, V. A. (1985). Identifying objects by touch: An

“expert system”. Perception & psychophysics, 37(4), 299-302

Moskowitz, H. R. (1977). Magnitude estimation: notes on what, how, when, and why to use

it. Journal of Food Quality, 1(3), 195-227.

Okamoto, S., Nagano, H., & Yamada, Y. (2012). Psychophysical dimensions of

tactile perception of textures. IEEE Transactions on Haptics, 6(1), 81-93.

Osgood, C. E., Suci, G. J., & Tannenbaum, P. H. (1957). The measurement of meaning (No.

47). University of Illinois press.

Posner, M. I. (1980). Orienting of attention. Quarterly journal of

experimental psychology, 32(1), 3-25.

Sathian, K., and A. Zangaladze. "Feeling with the mind's eye: contribution of visual cortex to

tactile perception." Behavioural brain research 135.1-2 (2002): 127-132.

Stevens, S. S., & Marks, L. E. (2017). Psychophysics: Introduction to its perceptual, neural,

and social prospects. Routledge.

Tanaka, Y., & Sukigara, S. (2008). Evaluation of “shittori” characteristic for fabrics. Journal of

Textile Engineering, 54(3), 75-81.

T. Verrillo, R., Bolanowski, S. J., & McGlone, F. P. (1999). Subjective magnitude of

tactile roughness. Somatosensory & Motor Research, 16(4), 352-360.

Tymms, C., Zorin, D., & Gardner, E. P. (2018). Tactile perception of the roughness of

3D-printed textures. Journal of neurophysiology, 119(3), 862-876.

Timm, F., & Kuehn, E. (2020). A Mechanical Stimulation Glove to Induce Hebbian

Plasticity at the Fingertip. Frontiers in Human Neuroscience, 14, 177.

Welch, R. B., DutionHurt, L. D., & Warren, D. H. (1986). Contributions of audition and

vision to temporal rate perception. Perception & psychophysics, 39(4), 294-300.

Yoshida, M. (1968). Dimensions of tactual impressions (1). Japanese Psychological

Research, 10(3), 123-137.

APPENDIX A

The following page below displays a copy of the information sheet, safety

questionnaire, consent form that were presented to participants before the

experiment.

GENERAL INFORMATION SHEET

Introduction to the Research:

You are a participant in this research study investigating Haptic perception which put simply

is the ability to tell the difference between a range of textures and whether this includes

other modalities such as Vision. The purpose of this investigation is to explore whether

vision has an influence on Haptic Perception.

What Stimuli will be presented?

The stimuli will involve 3D printed Blocks and will involve a lazy Susan which is a motorized

turntable and a blindfold.

What are the exclusion criteria?

The exclusion criteria are whether you are left-handed or if you have any injuries to your

fingers i.e., a cut or etc

Will my data be Kept Confidential?

The data collected from this experiment are compliant with the Data Protection Act 1998. All

information shared in this research will be kept strictly confidential.

Any Problems with the study you can contact Professor Max DI Luca who is the

lead supervisor in this research study. The email is M.DiLuca@bham.ac.uk.

You will be given a copy of this information sheet to keep if requested, Thanks for

your participation in this study and for taking the time to read this sheet.

PARTICIPANT CONSENT FORM

Participant code (researcher use):

Please put an X in the box for the following information where it applies to you:

male | female | Prefer not to say | Non-binary | Dominant Left | Right

Please initial each box to confirm the following:

Fluent | Yes | No
English
Speaker

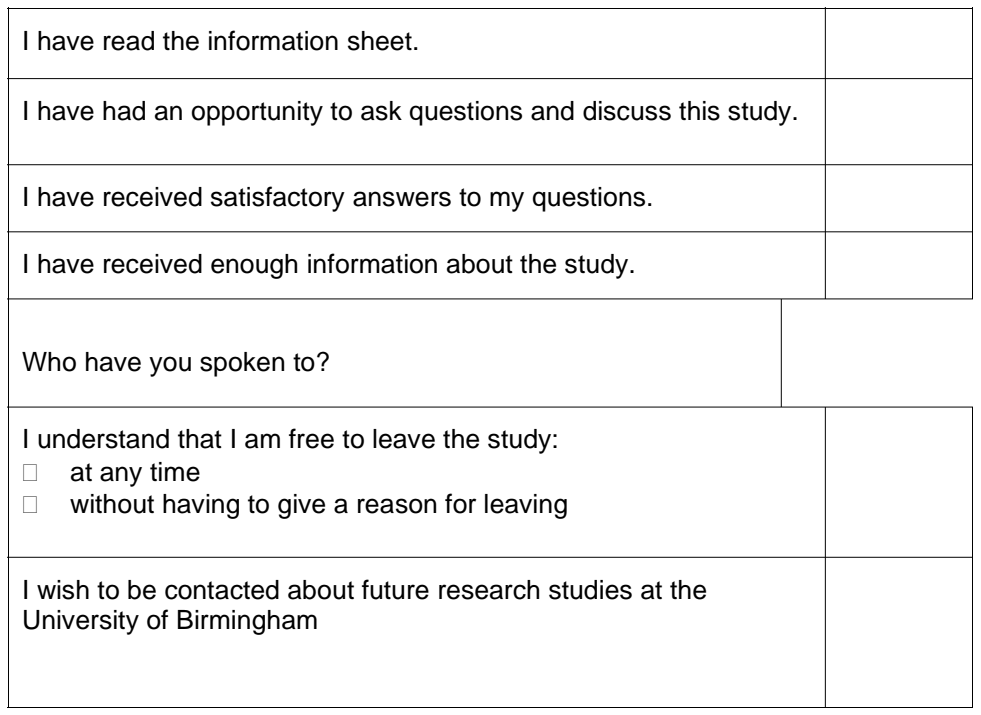
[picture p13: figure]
I have read the information sheet.; Who have you spoken to?; at any time; University of Birmingham

I have had an opportunity to ask questions and discuss this study.

I have received satisfactory answers to my questions.

I have received enough information about the study.

I understand that I am free to leave the study:

without having to give a reason for leaving

I wish to be contacted about future research studies at the

I confirm that I have read the participant information sheet and have completed the above consent form. The nature, purpose, and possible consequences of the procedures have been explained. I understand that I may withdraw from the study at any time. I confirm that I have been through the safety screening procedures if applicable and that I am happy to participate in this study.

Please note: All data arising from this study will be held and used in accordance with the Data Protection Act (2018). The results if the study will not be made available in a way that could reveal the identity of individuals.

Name in capital letters:
Signature: | Date:

Researcher witness (researcher use):
Print Name: | Signature:

Date:

Participant information sheet

This experiment is investigating whether vision has an influence on tactile perception to establish the thesis that Tactile perception is multifaceted and not unitary. You will complete three conditions with the same task of rating how rough the 3D samples are. The 3D samples will be presented on the Lazy Susan, and you will be asked to graze the sample with your index finger three times. Then you will be asked to rate the roughness of the sample presented on your own numerical scale, eg 25 for how rough the sample is.

Visual Condition:
You will be asked to report roughness based on the surface appearance alone without touching the sample

Visual Haptic condition:
You will be asked to graze the sample three times and report the roughness of the sample

Haptic Condition:

You will be blindfolded with consent and you will be asked to graze the sample three times and report the roughness of the sample.

APPENDIX B

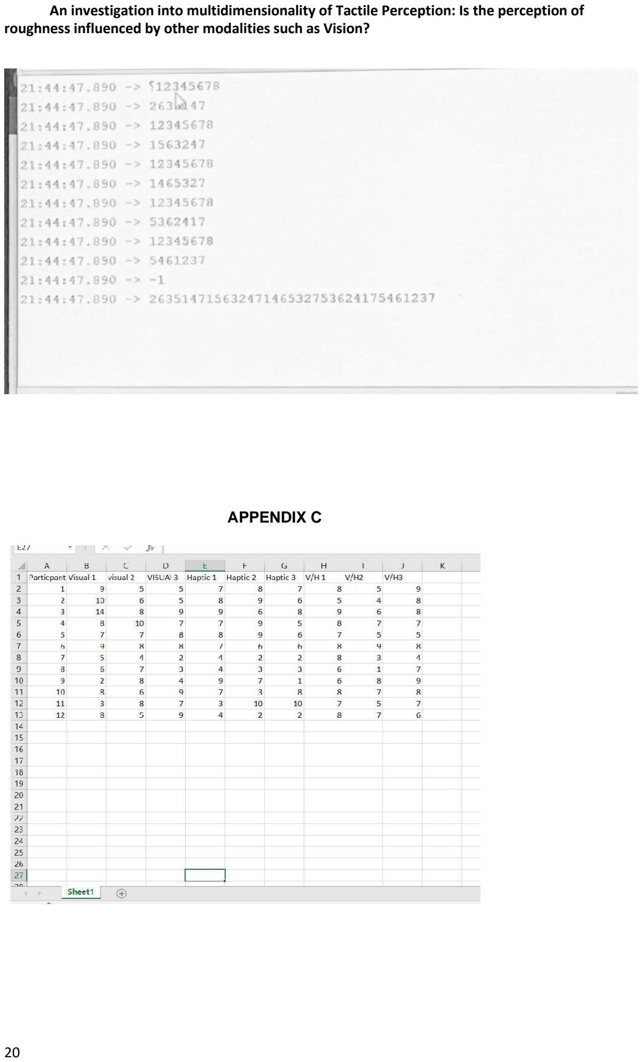
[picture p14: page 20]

APPENDIX C

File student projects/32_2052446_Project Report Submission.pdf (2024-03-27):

Does the amount of force used to press a surface alter roughness perception?

Student ID: 2052446

Word Count: 2964/4000

School of Psychology

University of Birmingham

Birmingham, UK

Finger Force and Roughness Perception

Abstract

This study investigated the influence of finger force on roughness perception. The experiment

had 30 participants, 11 were male and the rest were female. A repeated measures design was

used so all participants experienced both conditions. Participants pressed their finger onto

seven surfaces and gave each a roughness score. Participants were told to use either a high or

low force at the start of the experiment and alternated between the two forces every seven

trials until all trials were complete. The results showed that roughness perception was

significantly higher (p <.001 for surfaces 1-6, and p = .001 for surface 7) in the high force

condition compared to the low force condition. The results suggest that roughness perception

is influenced by the amount of force a person uses to press a surface. There are many

implications for this such as increasing our knowledge about how roughness is perceived,

contributing to our knowledge about tactile perception and providing useful information for

braille keyboard developers, smart phone developers and engineers. Future research should

investigate whether there is a difference in how roughness is perceived when pressing a surface

using different forces and sliding a finger across a surface using different forces.

Introduction

Tactile perception is part of a “complex human sensory system” that consists of four

main components: proprioception (body awareness), mechanoreception (touch),

thermoreception (temperature), and nociception (pain) (Schneider and Feussner, 2017). The

importance of developing tactile perception through life is highlighted in a review by Bremner

and Spence (2017) who illustrated that tactile perception provides people with a sensory

scaffold that allows them to perceive their own bodies and their sense of self. Kim and Cho

(2014) found that tactile perception stimulates cognitive thinking and influences problem-

solving skills in children, further highlighting the importance of developing tactile perception. A

study by Goldreich and Kanics (2003) found that blind people have enhanced tactile perception

compared to sighted people due to their reliance on tactile perception. This demonstrates how

important tactile perception is for blind people.

An article by Ardiel and Rankin (2010) illustrates the importance of tactile perception in

human development. In one section of the article, they highlight work by Casler (1965) who

found that when institutionalised infants received an additional 20 minutes of tactile

stimulation a day, they performed better on development assessments compared to

institutionalised infants who did not receive the additional tactile stimulation. The authors later

highlight research conducted by Field et al. (1986) and Scafidi et al. (1986) who both

investigated the effect that tactile stimulation would have on premature babies. The

researchers found that stroking the babies for 10 minutes a day led to better growth and

developmental performance compared to controls who did not receive the stroking. They also

found that the experimental premature babies were discharged earlier and spent more time awake and active compared to controls. The research illustrated in this article demonstrates

that touch plays a vital role in development.

There has been evidence to suggest that developing tactile perception can lead to

positive social outcomes. An experiment by Jakubiak and Feeney (2016) compared whether

imagined touch support or imagined verbal support was more effective in buffering stress. They

found that then when participants imagined touch support, stress was buffered better than

when they imagined verbal support or control imaginations. They also found that participants

displayed more enthusiasm for the tasks when imagining touch support. This demonstrates the

positive influence that developing tactile perception can have on people in a social aspect.

The benefits of tactile perception are further highlighted in an article by Bond (2002).

The article emphasised the benefits of touch for infants and parents by stating that massaging

infants can play an influential role in helping parents bond with their baby. An article by Feary

(2002) further highlighted the benefits of touch therapy, stating that it promotes bonding

between parents and their baby. These articles illustrate the importance of tactile perception as

it plays a role in creating and sustaining important familial bonds.

Roughness perception is one area that is influenced by tactile perception. Roughness is

described as the perception of a textured surface that has elements rising from the substance.

Lederman (1972) conducted an experiment to investigate some of the factors that influence

roughness perception. Participants ran three fingers across eight surfaces with varying groove

widths. The experiment had three different force conditions: the high force condition, the

normal force condition, and the low force condition. Participants were asked to give a roughness score for each surface. The results showed that perceived roughness increased with

groove width and finger force, suggesting both play a role in roughness perception.

The above experiment found that roughness perception is influenced by groove width.

To further investigate this finding, Sathian et al. (1989) conducted an experiment with the aim

of examining whether roughness perception increased with groove width. The experiment used

surfaces with varying groove widths that participants ran their finger across from behind a

curtain. They then assessed the roughness of each surface. The researchers found that

participants perceived a surface to be rougher when it had a larger groove width. This suggests

that groove width influences roughness perception.

Research has suggested that roughness perception can change depending on the

amount of force used to feel a surface. Lederman (1974) investigated this by having participants

place their arm on a balance arm and feel surfaces through a curtain. The balance arm is an

apparatus that requires a certain amount of force to be applied to it to stay balanced. The

amount of force required can be adjusted by adding or removing weights from it. The

experiment had three force conditions: the high force condition, the low force condition, and

the normal force condition. During the high and low force trials, the balance arm was adjusted,

and the participant had to apply either a high or low force on the surface to keep the balance

arm steady. During each trial, participants ran their middle finger across eight different metal

plates and gave a roughness score for each plate. The results showed that roughness scores

were higher in the high force trials compared to the other trials, providing further support for

the notion that finger force influences roughness perception.

While there is a large body of research that suggests finger force influences roughness

perception, the literature has focused on how roughness perception is influenced when people

slide their finger across surfaces using different forces. There is a lack of research on how

roughness perception can be altered when pressing a surface using different forces. As a result,

there is a gap in people’s understanding about roughness perception and this experiment aims

to bridge this gap by investigating if pressing a surface using different forces can influence

roughness perception.

The results obtained from this experiment will help researchers better understand

roughness perception and how finger force influences it. This would be useful to researchers

who plan to further investigate roughness perception. Roughness perception plays a key role in

engineering and a better understanding of it can be of use to engineers. Moreover, companies

that develop handheld items will benefit from these results as they can use this information to

make their items more comfortable to hold and to use.

As touch is the least explored of the senses, these results will provide a better overall

understanding of tactile perception. This can lead to the development of better braille

keyboards for blind people. As well as this, it could help researchers to better understand the

link between tactile perception and problem-solving skills. It can also lead to a better

understanding of the influence that tactile perception can have in a social setting. Furthermore,

understanding the importance of touch in parent-baby bonding and its positive influence on the

development of premature babies will be useful information for new parents.

Hypothesis

Roughness perception will increase when the finger force applied increases.

Methods

Participants

This experiment used a voluntary sample as it was the simplest to obtain. There was a

total of 30 participants (11 male) aged between 16 and 30. There were no specific requirements

to be eligible to take part in this experiment. Participants were presented with an information

sheet (Appendix A) that stated the purpose of the experiment and had instructions. They were

then given a consent form (Appendix B). Participants were told the true aim of the experiment

at the start and so could provide informed consent.

Material

The experiment used a Lazy Susan (Di Luca, 2022) that had seven surfaces with varying

groove widths and ridge heights attached to it (see Table 1). There were also two base surfaces,

one extremely rough and one smooth which were used to help participants learn the two

extreme ends of the scale. All the surfaces had a ridge width of 480μm. The surfaces were

made using a 3D printer. The results were analysed using SPSS.

| Ridge height (μm) | Groove width (μm)
Surface 1 | 536 | 680
Surface 2 | 632 | 1160
Surface 3 | 728 | 1640

Table 1 Depicts the ridge heights (μm) and the groove widths (μm) of the surfaces used in this experiment.

Procedure

The experiment consisted of two conditions: a high force condition and a low force

condition. The experiment had four blocks, each containing seven trials. A single trial consisted

of the participant pressing one of the seven surfaces and giving a roughness score. Each

condition was assessed twice so there were 28 trials in total. A pilot study had shown that

participants found the experiment to be quite tedious if there were many trials. As a result, this

experiment had 28 trials to ensure that the participants remained engaged during the

experiment. The experiment had a repeated measures design and used counterbalancing to

avoid order effects.

At the start of the experiment, participants pressed the upper part of their index finger

on the two base surfaces using a high and low force. Participants were told if they were starting

with the high or low force condition and alternated between the two forces after each block. A

pilot study showed that when participants were told to alternate between a high and low force

for each trial, they became confused about which force to use. To counter this problem,

participants were made to alternate between forces after each block instead of each trial.

Surface 4 | 824 | 2120
Surface 5 | 920 | 2600
Surface 6 | 1016 | 3080
Surface 7 | 1112 | 3560
Rough base surface | 1208 | 4040
Smooth base surface | 440 | 200

After feeling the two base surfaces, participants pressed the button on the Lazy Susan

which rotated and presented the participant with the surface that they needed to press.

Participants pressed the surface using the upper part of their index finger and then gave the

surface a roughness score ranging between 1 and 10. They repeated this process until all trials

were completed. The Lazy Susan was programmed to rotate between the seven surfaces in a

random order which was changed after each block.

Analysis

Before analysing the results, a test of normality was conducted to see if the data met

parametric assumptions. Table 2 shows that some parts of the data were normally distributed

while other parts were not normally distributed. As a result, the data did not meet parametric

assumptions.

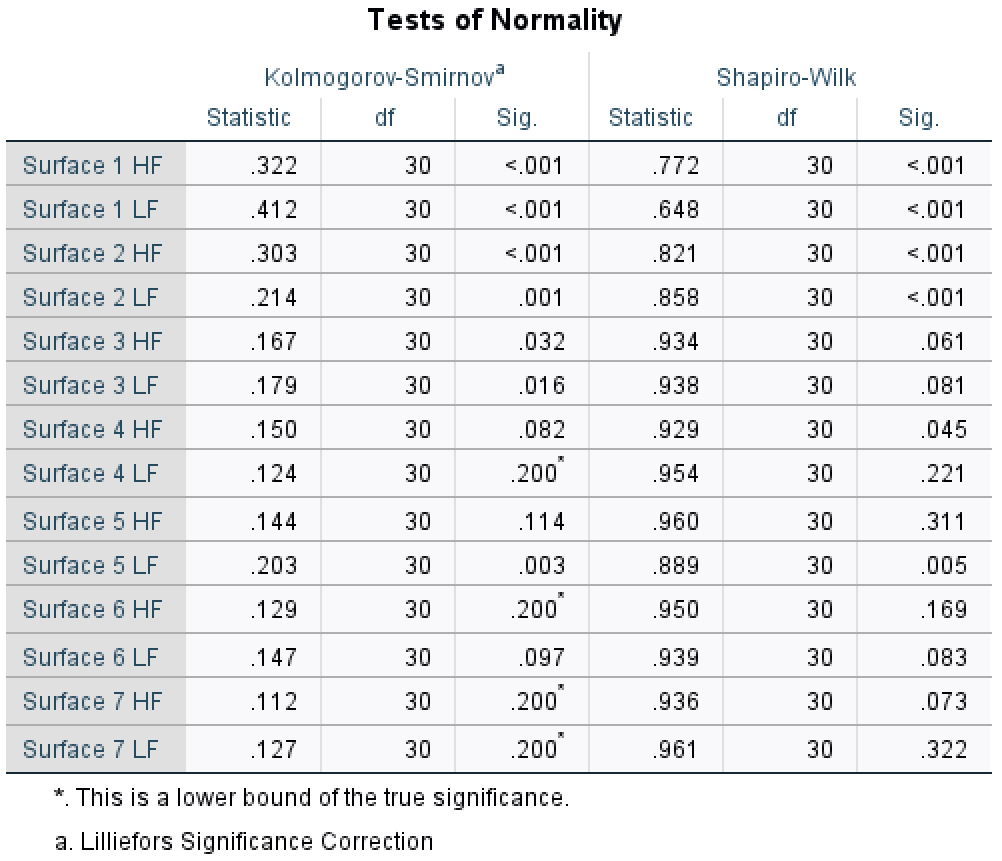
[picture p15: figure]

Table 2 Depicts the results from the test of normality. HF = High Force. LF = Low Force.

The data was analysed using the Wilcoxon Signed Ranks test on SPSS. This is because the

data did not meet parametric assumptions, all the participants took part in both conditions, and

a difference between the two conditions was being investigated. To conduct the Wilcoxon

Signed Ranks test, each participant’s average high force roughness score and average low force

roughness score for each surface was calculated.

Results

Figures 1 and 2 show the data obtained from this experiment. The figures clearly

demonstrate that a larger percentage of participants gave higher roughness scores in the high

force condition compared to the low force condition. They also show that while roughness

perception increased for each surface in both conditions, the increase is much more prominent

in the high force condition.

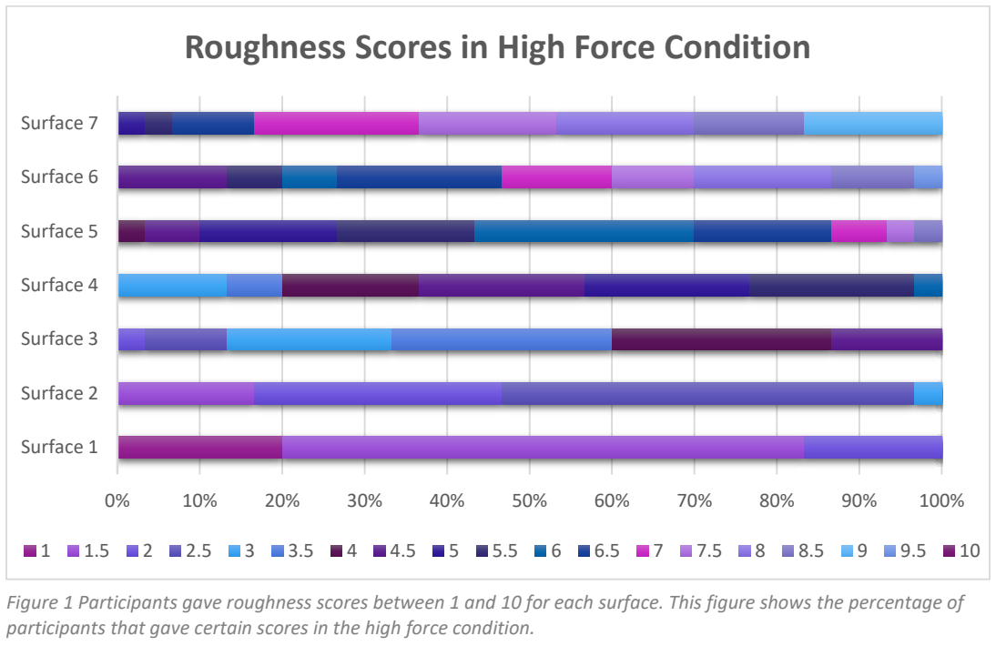
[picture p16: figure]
Surface 1; Surface 2; Surface 3; Surface 4; Surface 5; Surface 6; Surface 7

## Roughness Scores in High Force Condition

Figure 1 Participants gave roughness scores between 1 and 10 for each surface. This figure shows the percentage of participants that gave certain scores in the high force condition.

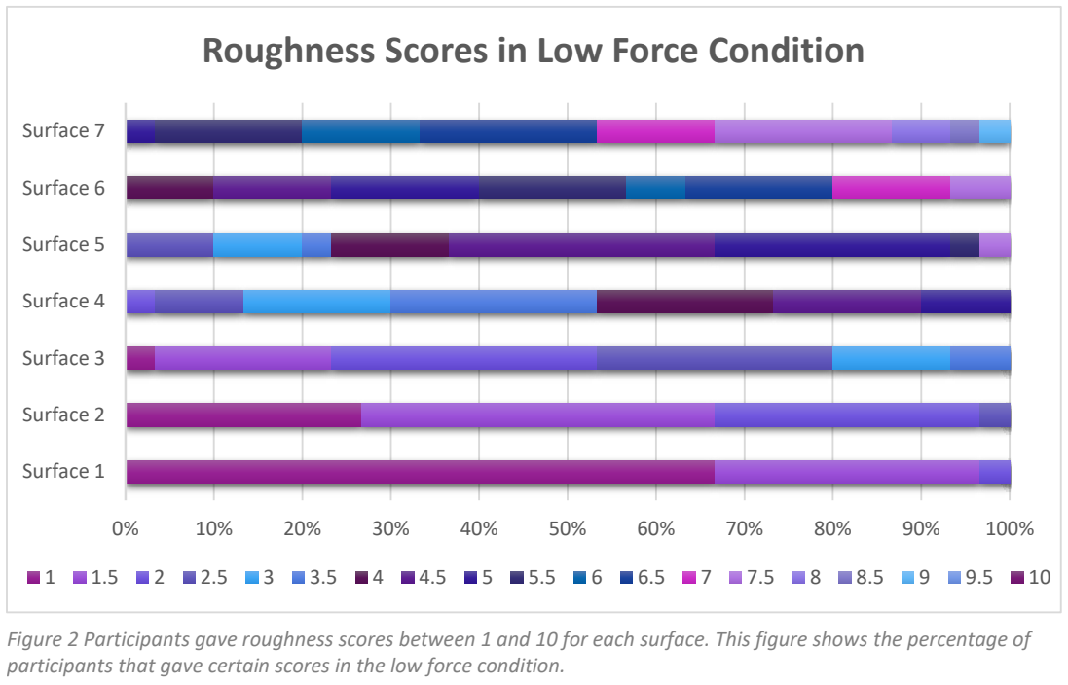
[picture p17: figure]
Surface 1; Surface 2; Surface 3; Surface 4; Surface 5; Surface 6; Surface 7; Roughness Scores in Low Force Condition

Table 3 shows that roughness perception significantly increased during the high force

condition for surface one (z = -3.626, p <.001), surface two (z = -4.597, p <.001), surface three (z

= -4.571, p <.001), surface four (z = -4.159, p <.001), surface five (z = -4.557, p <.001), surface six

(z = -3.518, p <.001), and surface seven (z = -3.255, p = .001). These results support the

hypothesis.

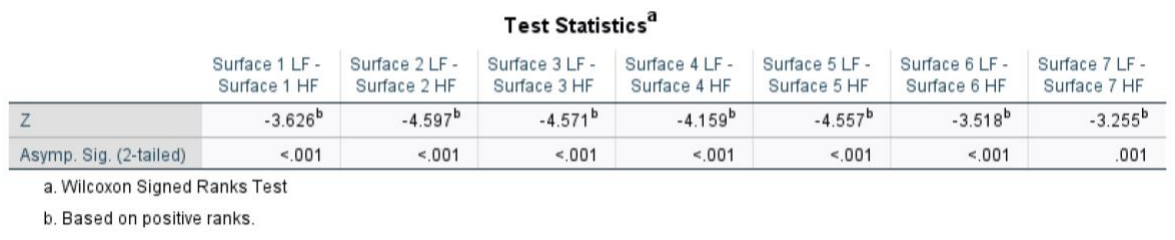
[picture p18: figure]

Table 3 Depicts the output of the Wilcoxon Signed Ranks test.

Figure 2 Participants gave roughness scores between 1 and 10 for each surface. This figure shows the percentage of participants that gave certain scores in the low force condition.

Discussion

The results obtained from this experiment show that finger force has a significant

influence on roughness perception, supporting this experiment’s hypothesis. These findings

have many implications for future research and people’s daily lives. The main implication of this

experiment is that it provides evidence to suggest that when a person presses a surface using

different forces, their perceived roughness of that surface will change. This addresses the gap in

the literature which focused on how sliding a finger across a surface using different forces

influences roughness perception but did not investigate if pressing a surface using different

forces would have the same influence.

As well as addressing the gap in the literature, the results obtained from this experiment

will provide researchers with more information about how people perceive roughness. This

information could be of use to researchers who plan to conduct further experiments on

roughness perception. The researchers would have to take these findings into account when

conducting future experiments on roughness perception. These findings could also inspire

researchers to think of other research questions related to roughness perception that need

investigating. One aspect to investigate could be comparing if there is a difference in how

roughness is perceived when pressing a surface using different forces compared to sliding a

finger across the same surface using different forces.

Another consequence of this research is that it can help researchers to better

understand touch and how tactile perception works. An improved understanding of tactile

perception is something researchers should aim to work towards. This is because tactile perception influences many areas of human life such as problem-solving skills (Kim and Cho,

2014), parent-baby bonding (Bond, 2002; Feary, 2002), and can positively influence the growth

and development of premature babies (Field et al., 1986; Scafidi et al., 1986). As well as this, it

can have a positive effect on institutionalised infants (Casler, 1965), can reduce people’s stress

in social situations (Jakubiak and Feeney, 2016), and provides people with a sensory scaffolding

that allows them to perceive themselves (Bremner and Spence, 2017). Improved understanding

of tactile perception can help better understand how and why tactile perception plays a role in

so many different aspects of human life and can lead to the development of methods and

techniques to positively influence these aspects.

Furthermore, these findings may be of use for people who develop braille keyboards

and other braille systems. This is due to these systems requiring blind people to press their

fingers onto the braille patterns to be able to read and write. Insight about how the perception

of a surface’s roughness can change when pressing that surface using different forces is

information that braille system developers could consider during development to create better

and more efficient systems.

A further implication of this research is the benefits it would provide to companies that

develop smart phones. Smart phones are used by pressing one’s finger on the screen to do

different things. Knowledge about how a person’s perception of roughness can change when

they use a different force to press the screen is something companies can consider during

development stages to ensure they create a device that is comfortable to use. This could also

apply to other companies that specialise in developing handheld items other than

smartphones.

Moreover, these findings would be of benefit to engineers. When making decisions

about building new structures, engineers will have to take the roughness of materials into

account before deciding which material to use. This is because rougher materials wear away

easier than less rough materials so engineers will usually avoid the use of rougher materials.

Engineers will be better able to assess the roughness of a material if they are informed that

pressing materials using different forces will influence their perception of roughness.

A limitation of this study is that there were few trials to examine roughness perception.

While the number of trials was decided on to ensure that the participants remained engaged

during the experiment, it limited how much data could have been obtained. This should not

affect the validity of the data as a large sample size was used which should make up for the

small number of trials. However, researchers should still try to address this to be sure that this

is the case. To address this, researchers should replicate this study using more trials and should

see whether the results from this experiment are replicated. To counter the problem of

participants feeling bored or losing interest, the researchers could try spreading the experiment

out over several days and conduct a few trials each day.

Another problem with this experiment was that there was no way to control how much

force the participants used in the different conditions. It is highly likely that the participants did

not all use the same amount of force in the high force condition or the same amount of force in

the low force condition. To account for this, researchers should replicate this study while

making use of the balance arm used by Lederman (1974) to ensure participants all use the same

amount of force when pressing the surfaces in the different conditions. Doing this would

increase the validity of the results.

While this experiment does have some limitations, the experiment also has several

strengths. As mentioned before, the experiment has a sample size of 30 people which is much

larger than the samples used by Lederman (1972,1974) and Sathian et al. (1989). A larger

sample size increases the accuracy of the data obtained which makes the results more valid.

Furthermore, the conditions were counterbalanced which ensured that the participants did not

display order effects. It also minimised the risk of the data being influenced by extraneous

factors such as practice. As well as this, the Lazy Susan was programmed to rotate and present

the participants with the surfaces in a random order which was changed after every block.

Doing this ensured that the participants did not work out which of the seven surfaces they were

feeling. It also ensured that the order that participants felt the surfaces in during each block

was different, further reducing the likelihood of the participants predicting the order of the

surfaces. This was important as it reduced the participant’s ability to alter their responses in a

favourable way or a way that could sabotage the results.

Overall, this study aimed to investigate whether finger force would alter roughness

perception and the results obtained suggest that this is the case. Researchers should try to

replicate this study to confirm the reliability of these results. They should also investigate

whether roughness perception changes when pressing a surface using more than just two

forces. They should make use of a balance arm during these experiments. A final aspect that

researchers should investigate is if there is a difference in how roughness is perceived when

pressing a surface using different forces and sliding a finger across a surface using different

forces.

References

Ardiel, E. L., & Rankin, C. H. (2010). The importance of touch in development. Paediatrics & child

health, 15(3), 153-156. https://doi.org/10.1093/pch/15.3.153

Bond, C. (2002). Baby massage: a dialogue of touch. The Journal of Family Health Care, 12(2), 44-47.

PMID: 12415754.

Bremner, A. J., & Spence, C. (2017). The development of tactile perception. Advances in child

development and behavior, 52, 227-268. https://doi.org/10.1016/bs.acdb.2016.12.002

Casler, L. (1965). The effects of extra tactile stimulation on a group of institutionalized infants. Genetic

Psychology Monographs.

Di Luca, M. (2022, April 4). Arduino-based Lazy Susan. LazySusan.

https://maxdiluca.github.io/LazySusan/

Feary, A. M. (2002). Touching the fragile baby: looking at touch in the special care nursery

(SCN). Australian Journal of Holistic Nursing, The, 9(1).

https://search.informit.org/doi/10.3316/informit.493333214836258

Field, T. M., Schanberg, S. M., Scafidi, F., Bauer, C. R., Vega-Lahr, N., Garcia, R., ... & Kuhn, C. M. (1986).

Tactile/kinesthetic stimulation effects on preterm neonates. Pediatrics, 77(5), 654-658.

https://doi.org/10.1542/peds.77.5.654

Goldreich, D., & Kanics, I. M. (2003). Tactile acuity is enhanced in blindness. Journal of

Neuroscience, 23(8), 3439-3445. https://doi.org/10.1523/JNEUROSCI

Jakubiak, B. K., & Feeney, B. C. (2016). Keep in touch: The effects of imagined touch support on stress

and exploration. Journal of Experimental Social Psychology, 65, 59-67.

https://doi.org/10.1016/j.jesp.2016.04.001

Kim, M. J., & Cho, M. E. (2014). Studying children's tactile problem-solving in a digital

environment. Thinking Skills and Creativity, 12, 1-13. https://doi.org/10.1016/j.tsc.2013.11.001

Lederman, S. J. (1974). Tactile roughness of grooved surfaces: The touching process and effects of

macro-and microsurface structure. Perception & Psychophysics, 16(2), 385-395.

https://doi.org/10.3758/BF03203958

Lederman, S. J., & Taylor, M. M. (1972). Fingertip force, surface geometry, and the perception of

roughness by active touch. Perception & Psychophysics, 12(5), 401-408.

https://doi.org/10.3758/BF03205850

Sathian, K., Goodwin, A. W., John, K. T., & Darian-Smith, I. (1989). Perceived roughness of a grating:

correlation with responses of mechanoreceptive afferents innervating the monkey's

fingerpad. Journal of Neuroscience, 9(4), 1273-1279. https://doi.org/10.1523/JNEUROSCI

Scafidi, F. A., Field, T. M., Schanberg, S. M., Bauer, C. R., Vega-Lahr, N., Garcia, R., ... & Kuhn, C. M.

(1986). Effects of tactile/kinesthetic stimulation on the clinical course and sleep/wake behavior

of preterm neonates. Infant behavior and development, 9(1), 91-105.

https://doi.org/10.1016/0163-6383(86)90041-X

Schneider, A., & Feussner, H. (2017). Mechatronic Support Systems and Robots. Biomedical Engineering

in Gastrointestinal Surgery, 387–441. https://doi.org/10.1016/b978-0-12-803230-5.00010-5

Appendix A

Information Sheet

The aim of this study is to investigate whether a person’s roughness perception is influenced by the amount of force they use to press a surface. The experiment should take no more than 15 minutes and your data will be anonymous. You are not required to take part in this study.

Instructions

You will press the top part of your index finger on two base surfaces using a high and low force.

You will be told if you will be starting in the high or low force condition.

You will then press a button on the Lazy Susan which will rotate and present you with one of seven surfaces to press.

You will give a roughness score between 1 and 10 for the surface you have pressed.

You will repeat this process for all seven surfaces.

You will then press all seven surfaces again using a different force. If you started in the high force condition, you will now be using a low force and vice versa.

Each condition will be tested twice; there will be 28 trials. You will use a high force for half of these trials and a low force for the other half of these trials.

Appendix B

Consent Form
Your responses in this experiment will remain confidential and will not be associated with your name. You are allowed to stop participating in the experiment at any point should you feel uncomfortable. Should you choose to stop taking part, your data will be discarded, and you will not be penalised for this. Your participation in this study should take no more than 15 minutes. If you have any concerns about this study, please contact me via email:
Uzma Kauser – UXK846@student.bham.ac.uk

I understand that my participation in this experiment is voluntary.
Please circle Yes or No.

I understand that my data will remain confidential and will not be associated with me. Please circle Yes or No.

I understand that I can withdraw from the experiment at any point and will not be penalised for it.
Please circle Yes or No.

I understand my rights and consent to take part in this experiment.
Please circle Yes or No.

Please sign below to confirm that you would like to take part in this experiment.

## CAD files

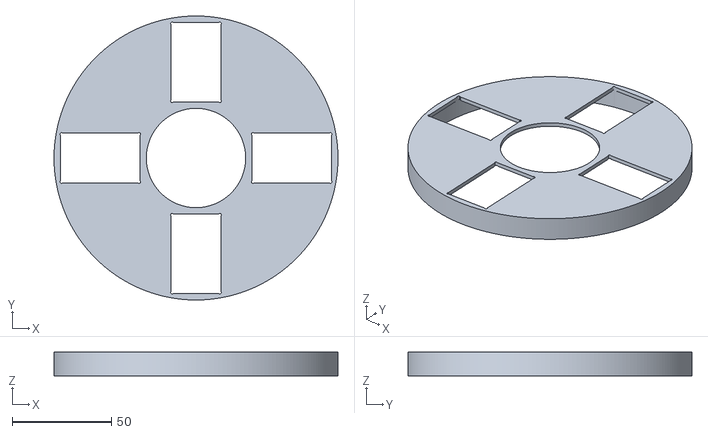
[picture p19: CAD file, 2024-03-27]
3D printing/susanholder4_25_40.stl
143.0 x 143.0 x 12.0

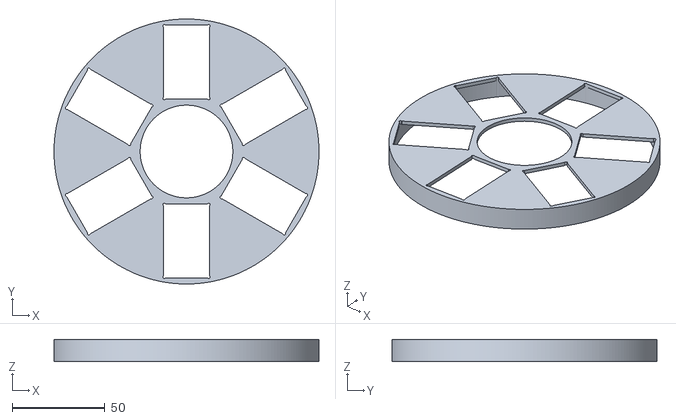
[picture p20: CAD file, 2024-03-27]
3D printing/susanholder6_25_40.stl
143.0 x 143.0 x 12.0

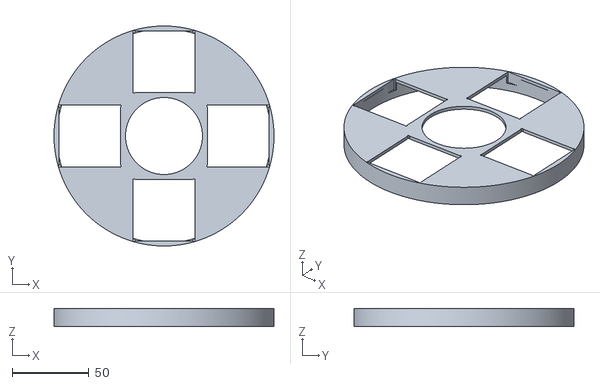
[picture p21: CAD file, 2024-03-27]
3D printing/susanholder4_40_40.stl
143.0 x 143.0 x 12.0

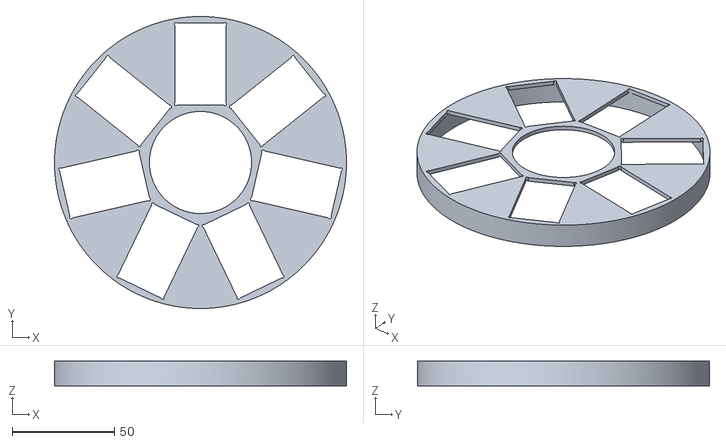
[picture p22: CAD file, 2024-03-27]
3D printing/susanholder7_25_40.stl
143.0 x 143.0 x 12.0

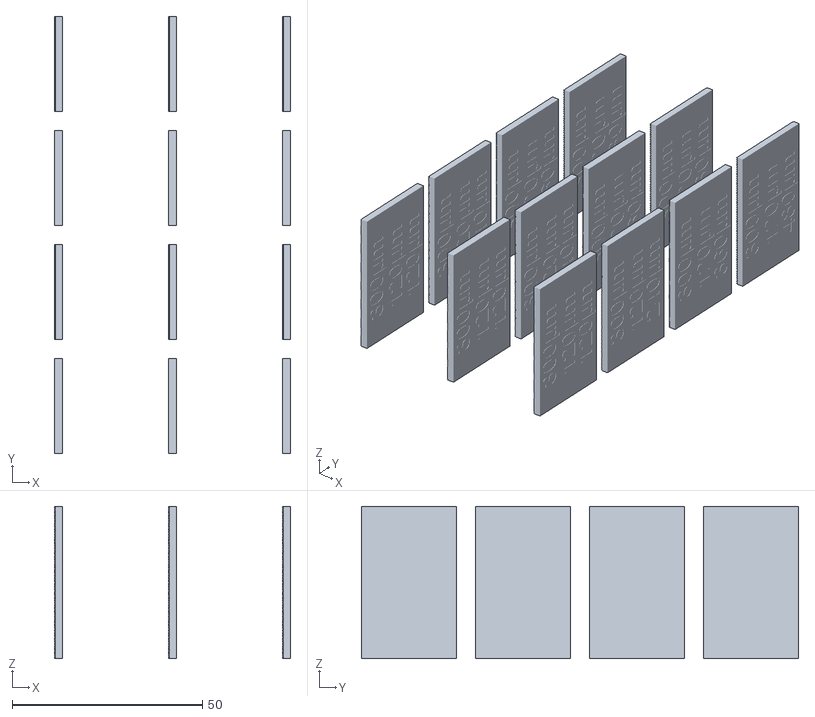
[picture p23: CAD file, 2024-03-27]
3D printing/1Dtextures.stl
62.1 x 115.0 x 40.0

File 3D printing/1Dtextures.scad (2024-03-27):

/*Creates a 1d texture wit equally-spaced ridges
Massimiliano Di Luca
m.diluca@bham.ac.uk
September 10, 2020*/

//measures in millimiters

gmin=120;
gstep=120;
gmax=500;


repetitions=3;




ridge=.12;

w=25;
l=40;
hbase=1.8;
hridges=.3;
        
        
        
        
for (n=[1:1:repetitions]){
    for (g=[gmin:gstep:gmax]){
        translate([n*30,(g-gmin)/gstep*30,0])
        rotate([0,90,180])
texture(g/1000);
    }
}

//groove=1.2;


        
        
        module texture(groove){

//center the texture elements on the base
texturestart=((l-ridge)%(groove+ridge))/2;

 
   
difference(){
translate([0,0,hbase]){
union(){
    translate([-l/2,-w/2,-hbase])
    cube([l,w,hbase]);

for (p=[texturestart:(groove+ridge):l-ridge]){
    translate([p-l/2,-w/2,-.1])
        cube([ridge, w, (hridges +.1)]);
     
}
}
};
  
rotate([180,0,180])
translate([0,-w/2+2,-.1])
linear_extrude(11){
  text(text = str(groove*1000,"µm"), font = "Arial", size = 6, halign =  "center");
    }

rotate([180,0,180])
translate([0,-3,-.1])
linear_extrude(11){
  text(text = str(ridge*1000,"µm"), font = "Arial", size = 6, halign =  "center");
    }
    
    rotate([180,0,180])
translate([0,w/2-7,-.1])
linear_extrude(11){
  text(text = str(hridges*1000,"µm"), font = "Arial", size = 6, halign =  "center");
    }

}
}

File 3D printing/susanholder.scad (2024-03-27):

//number of samples
nd=4;
//size of the samples
w=25;
h=40;



dan=360/nd;


thicknesstop=2;

brimthichnkess=2;
brimheight=10;
diametersusan=139;



difference(){
         translate([0,0,-brimheight])
            cylinder(brimheight+thicknesstop,d=brimthichnkess*2+diametersusan,$fn=200);
   
    union(){
       for(a=[0:dan:359.9]){
        rotate([0,0,a]){
           translate([-w/2,h/2+8.2,-5]){
            cube([w,h,10]);
               translate([w/2,h/2,0]){
          for (x=[-w/2+.5,w/2-.5]){
             for (y=[-h/2+.5,h/2-.5]){
                 translate([x,y,-10])
                cylinder(20,.8,.8,$fn=20);
             }
         }
     }
 }
 }
        };
        translate([0,0,-300])
         cylinder(400,d=50,$fn=200);
   
             translate([0,0,-400])
         cylinder(400,d=diametersusan,$fn=200);
  
    };

    
}

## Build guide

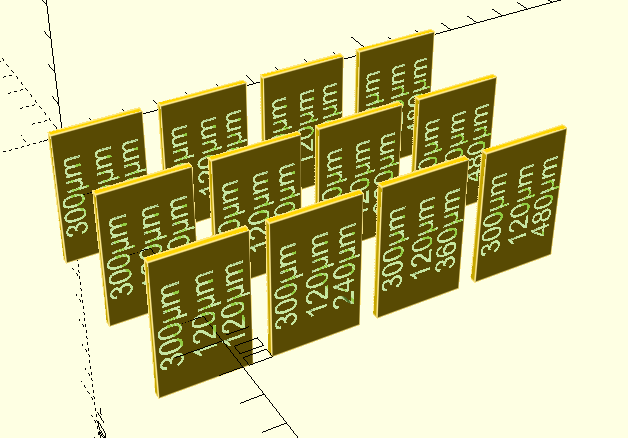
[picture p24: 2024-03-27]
3D printing/Screenshot 2024-03-27 at 15.06.16.png

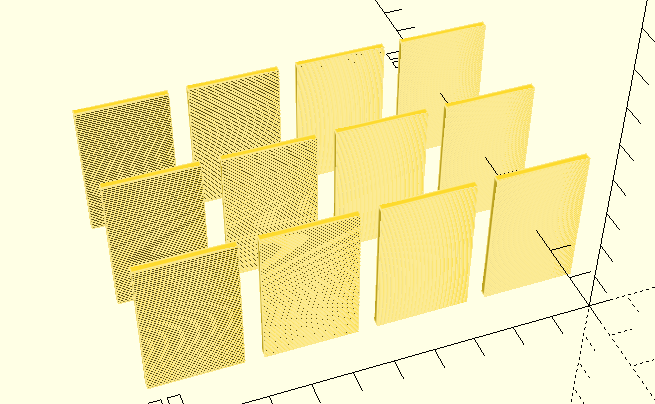
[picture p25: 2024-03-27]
3D printing/Screenshot 2024-03-27 at 15.06.27.png

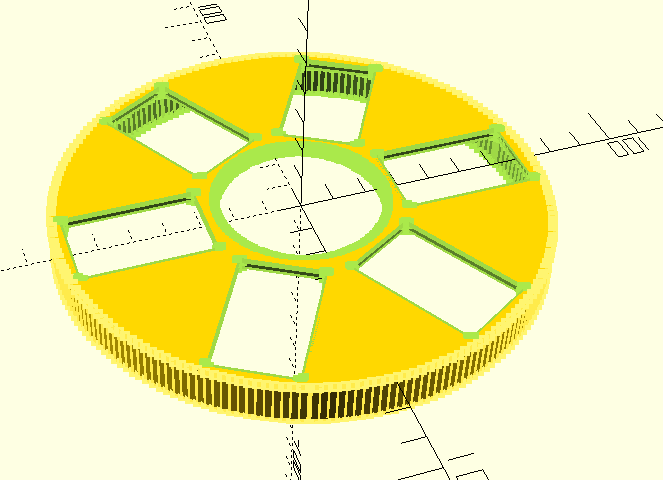
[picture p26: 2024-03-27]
3D printing/Screenshot 2024-03-27 at 14.50.04.png

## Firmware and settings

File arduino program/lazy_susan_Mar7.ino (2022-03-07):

#include <Stepper.h>
#include <ezButton.h>

// parameters
int seed = 1;
const int n_stimuli = 7;
const int n_repetitions = 5;
const int n_trials = n_stimuli * n_repetitions;

// hardware variables
const int stepsPerRevolution = 32;  // change this to fit the number of steps per revolution
const int gearRed = 64; // for your motor
const int stepsPerOutRev = stepsPerRevolution * gearRed;
const int stepsperdivision = stepsPerOutRev / n_stimuli;
const int ledPin = 13;      // pin 13 has the internal and the external LED attached to it
const int pushButton = 12; // digital pin which has a pushbutton attached to it
ezButton button(pushButton);
//2048
//2ms
//500s/s
//4s rotation
// initialize the stepper library on pins 2 through 5
Stepper myStepper(stepsPerRevolution,    5, 3, 2, 4);


// randomization variables
long randNumber;
int f;
int i;
int n;
int chosen_element;
int chosen_position;
int r;
int x;
int count = 0;


// trials variables
int randomized_trials[n_stimuli * n_repetitions];
int ordered_array[n_stimuli + 1];

// control of the trial variables
int currentstepangle;
int desiredstepangle;
int trialcount = -1;
int buttonState;





void setup() {


  // initialize
  Serial.begin(115200); //serial connection needs to be higher than 9600 as otherwise some of the numbers are not outputed correctly
  pinMode(ledPin, OUTPUT); //hardware setup
  button.setDebounceTime(50); // set debounce time to 50 milliseconds

  randomSeed(seed);//analogRead(0)); //usually randomized


  digitalWrite(ledPin, LOW); //turn off LED



  //create an array of stimuli
  for ( r = 0; r < n_repetitions; r = r + 1)
  {

    //define series of ordered stimuli for each repetition
    for ( i = 0; i < n_stimuli + 1; i = i + 1) {
      ordered_array[i] = i + 1;
      // Serial.print(ordered_array[i]);
    }
    //  Serial.println(" ");

    for (n = n_stimuli - 1; n > -1; n--) // here we pick random elements in the array until we got 'em all
    {
      chosen_position = random(n);
      chosen_element  = ordered_array[chosen_position];
      randomized_trials[count] = chosen_element ;
      count = count + 1;
      //    Serial.print( chosen_element );
      for ( x = chosen_position; x < n; x++) // here we shift all elements (who come AFTER the chosen one) in the array one place to the left
      {
        ordered_array[x] = ordered_array[x + 1];
      }

    }

    Serial.println(" ");


  }
  // Serial.println(-1);
  for ( i = 0; i < (n_trials); i = i + 1) {
    Serial.print(randomized_trials[i]);

  }
  Serial.println(" ");



  delay(500);



  //ask to press and release the button to check that it works, while the led flashes
  button.loop(); // MUST call the loop() function first
  int buttonState = button.getState();

  // wait until the button is pressed
  while (buttonState == 0)
  {
    button.loop(); // MUST call the loop() function first
    buttonState = button.getState();
    digitalWrite(ledPin, HIGH);
    delay(100);
    digitalWrite(ledPin, LOW);
    delay(50);
  }

  // check that the button is released
  digitalWrite(ledPin, LOW);
  while (buttonState == 1)
  {
    button.loop();
    buttonState = button.getState();

  }


  // flash three times
  delay(200);
  for ( i = 0; i < 3; i = i + 1)
  {
    digitalWrite(ledPin, HIGH);
    delay(500);
    digitalWrite(ledPin, LOW);
    delay(200);
  }

  // ready to go
  delay(1000);
  currentstepangle = 0;



}




void loop() {


  if (trialcount < n_trials) {
    myStepper.setSpeed(800);//trial and error max 1100


    /*// this code was meant to find the best direction to turn
      if (abs(desiredstepangle-currentstepangle)<abs(stepsPerOutRev-(desiredstepangle-currentstepangle)))
      {
      Serial.println("clockwise");
      myStepper.step(desiredstepangle-currentstepangle);

      }else{
      Serial.println("counter-clockwise");
       myStepper.step(stepsPerOutRev-(desiredstepangle-currentstepangle));
      }*/
    desiredstepangle = stepsperdivision * randomized_trials[trialcount];
    myStepper.step(desiredstepangle - currentstepangle);

    // debug printing
    // Serial.print(currentstepangle);
    // Serial.print(desiredstepangle);
    // Serial.println(desiredstepangle - currentstepangle);



    //indicate to the participant how long to touch the sample for
    digitalWrite(ledPin, HIGH);
    delay(2000);
    digitalWrite(ledPin, LOW);
    delay(2000);


    //start flashing to wait for a button press and release to advance to next trial
    button.loop(); // MUST call the loop() function first
    int buttonState = button.getState();

    // wait until the button is pressed
    while (buttonState == 0)
    {
      button.loop(); // MUST call the loop() function first
      buttonState = button.getState();
      digitalWrite(ledPin, HIGH);
      delay(100);
      digitalWrite(ledPin, LOW);
      delay(100);
    }
    digitalWrite(ledPin, LOW);


    // check that the button is released
    while (buttonState == 1)
    {
      button.loop(); // MUST call the loop() function first
      buttonState = button.getState();

    }


    // advance to next trial
    delay(100);
    trialcount = trialcount + 1;
    currentstepangle = desiredstepangle;

  }





}
